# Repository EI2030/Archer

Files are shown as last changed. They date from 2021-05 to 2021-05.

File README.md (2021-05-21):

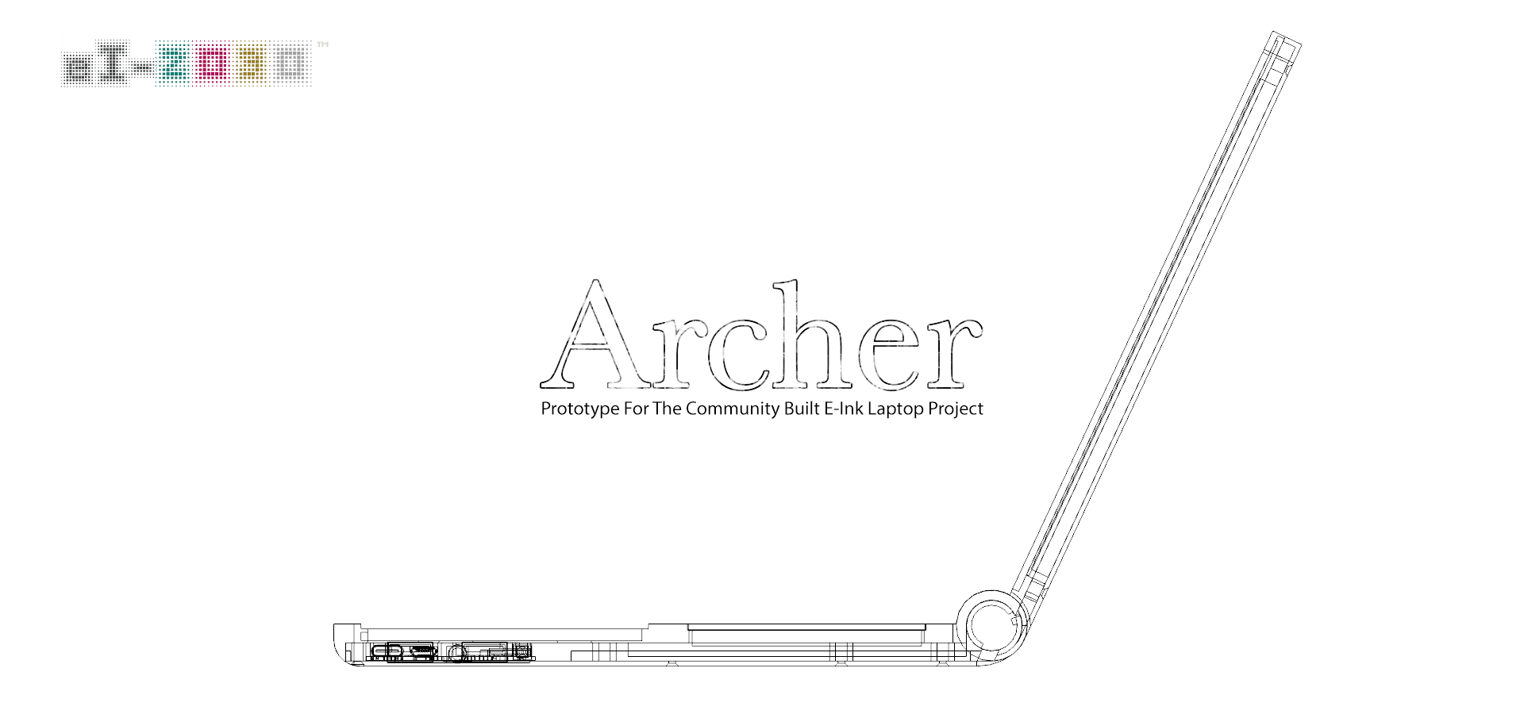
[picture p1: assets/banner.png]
banner


Archer is the codename of our 1st EPD laptop prototype with custom-designed motherboard and 3D-printed chassis.

# Specifications

The specification listed are preliminary and subject to change. Note this is only the specification for the prototype, it does **not** represent the spec for the final product.

- SoC: NXP i.MX 7Dual (2x ARM Cortex-A7 @ 1.2GHz)
- RAM: 2x Micron MT41K256M16 (1GB in total, DDR3)
- Flash: None (prototype designed to always boots from TF card)
- HDD: None
- Network: RTL8273BS (802.11n + BT)
- Main Screen: E Ink ED103TC2 (10.3" 1872x1404) with capactive touch screen
- Sub Screen: ER-TFT0784-1 (7.84" 1280x400) with capactive touch screen
- Screen Controller: i.MX7 integrated EPDC
- Battery: 2x User replaceable LiFePO4 18650 battery
- EC: LPC55S28
- Ports:
  - USB 2.0 Type A Host x1
  - USB 2.0 Type C UFP with Power Delivery x1
  - USB 2.0 Micro B Serial Debug Console x1
  - TF card slot

# Goals

## Goals of this prototype

- Proof of Concept of a EPD laptop
- Enable early development of EC firmware
- Enable early development of the user software
- Test chassis design ideas
- Verify peripheral circuit design
- Enable future prototype with final processor choice

## Non-Goals

- Archer will not represent the performance level of the final product
- Archer is not optimized for low power consumption

# Progress

## Chassis

R0.1 chassis design in progress. Not yet printed.

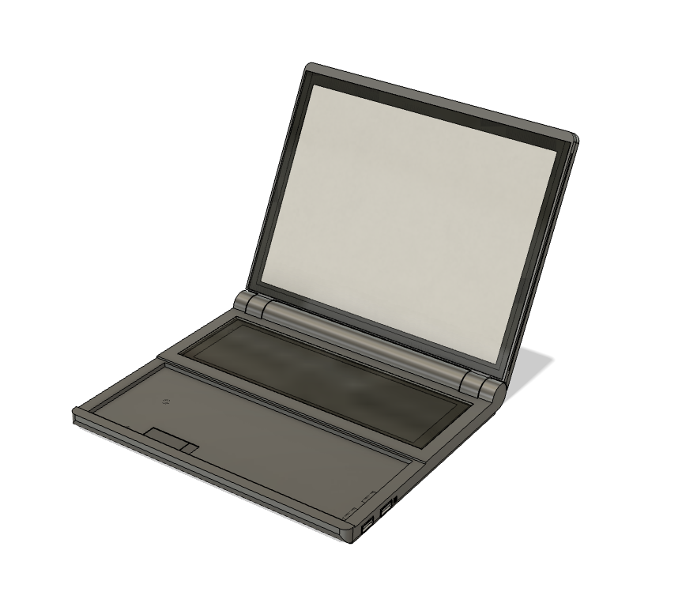
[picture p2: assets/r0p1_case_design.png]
case-design


## Motherboard

R0.1 PCB design finished. Sent to fab.

# Legalese

E Ink® is a registered trademark by E Ink Corporation. All other trademarks are property of their respective owner.

# License

The hardware design is released under the CERN Open Source Hardware License strongly-reciprocal variant, CERN-OHL-S. A copy of the license is provided in the source repository. Additionally, user guide of the license is provided on ohwr.org.

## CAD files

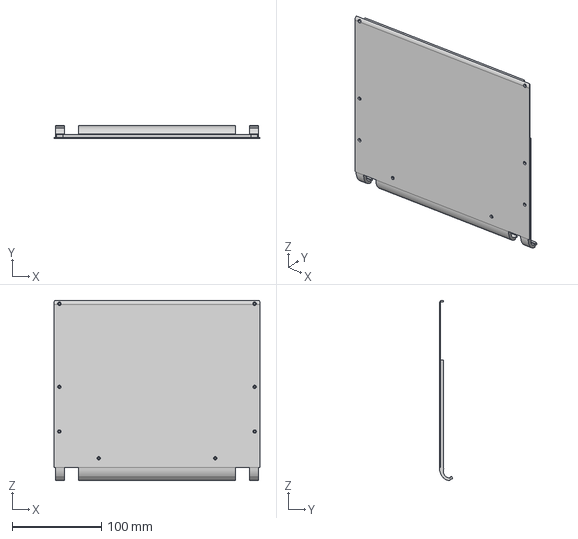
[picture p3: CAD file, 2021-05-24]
chassis/D_case.step
230.6 x 15.0 x 201.8 mm

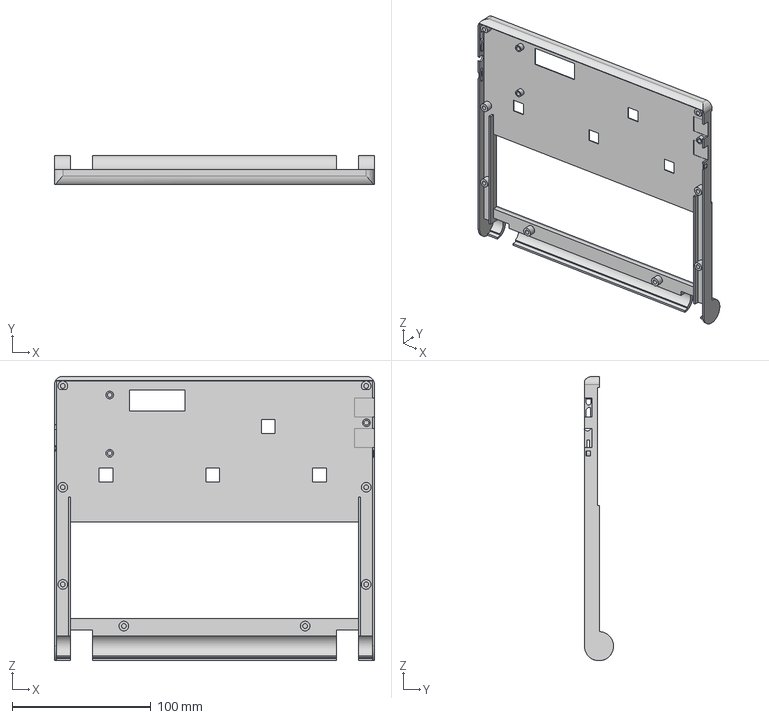
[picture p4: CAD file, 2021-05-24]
chassis/C_case.step
230.6 x 21.0 x 205.0 mm

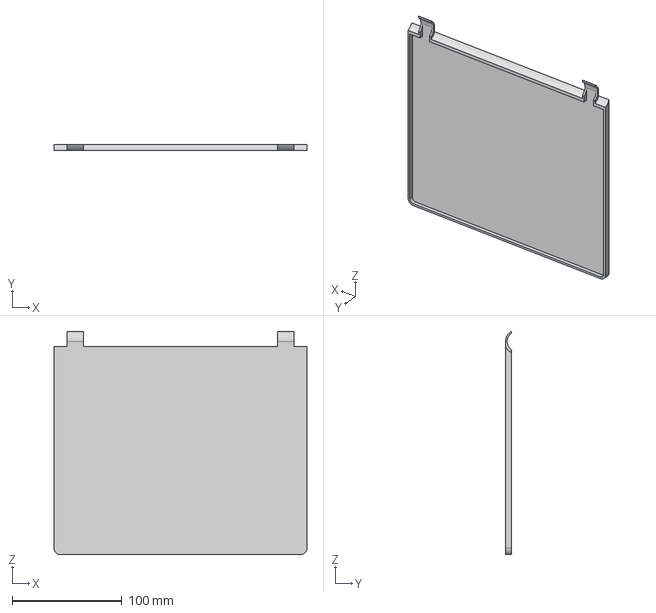
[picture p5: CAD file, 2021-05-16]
chassis/A_case.step
230.6 x 5.40 x 203.7 mm

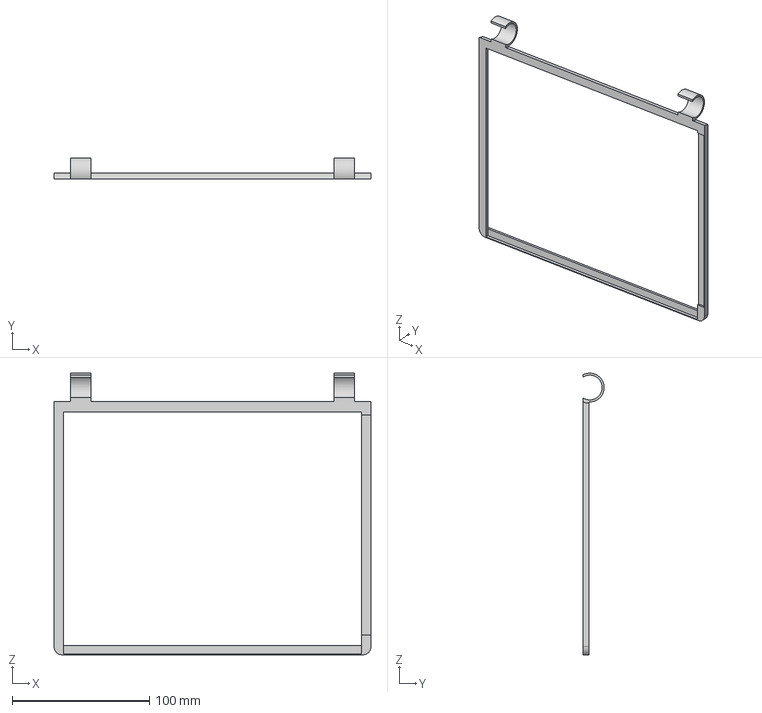
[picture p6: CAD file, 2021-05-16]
chassis/B_case.step
230.6 x 15.6 x 205.0 mm

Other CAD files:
chassis/A_case.f3d
chassis/B_case.f3d
chassis/C_case.f3d
chassis/D_case.f3d

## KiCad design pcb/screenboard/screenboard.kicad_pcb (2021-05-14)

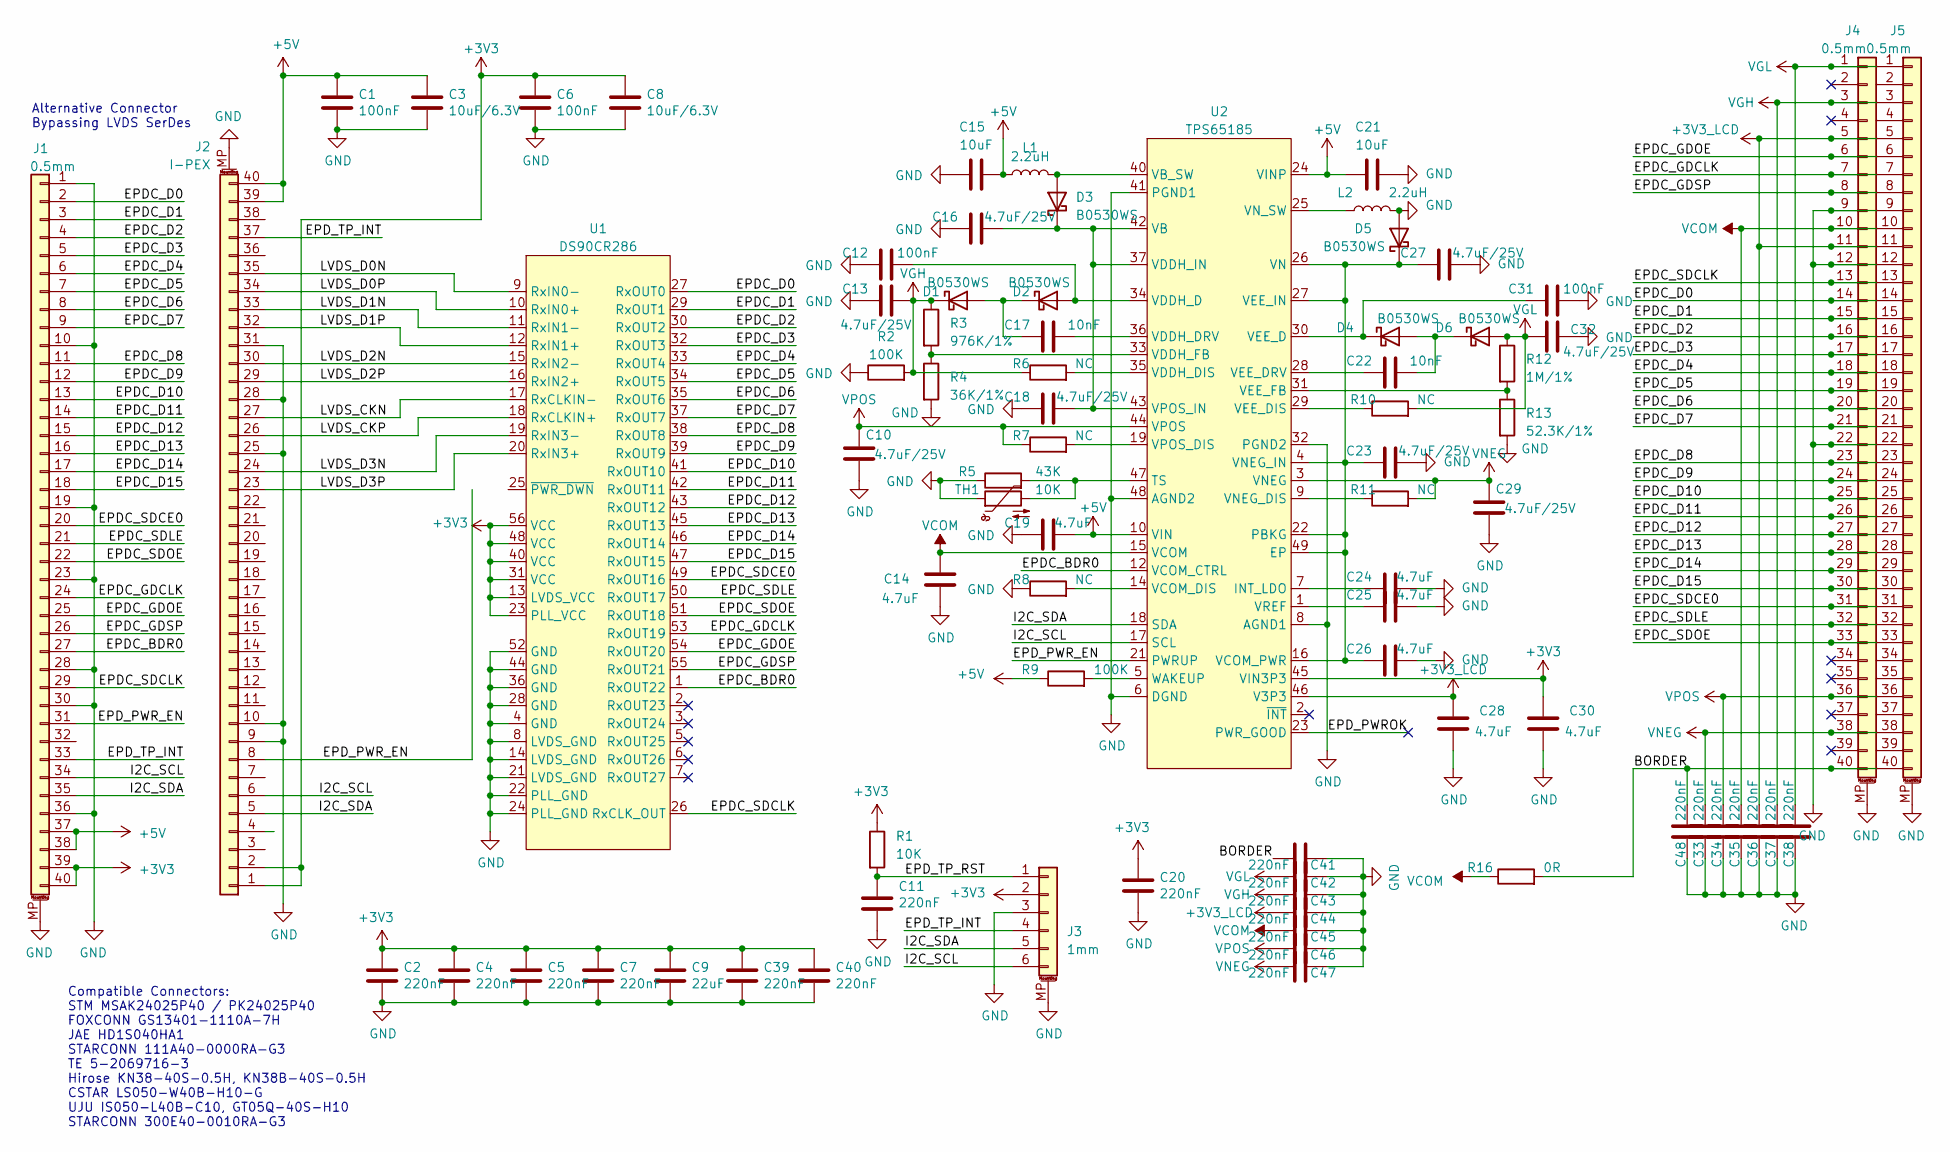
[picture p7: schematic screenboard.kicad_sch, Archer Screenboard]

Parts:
C1, C6, C12, C31: 100nF; C_0402_1005Metric
C2, C4, C5, C7, C11, C20, C33, C34, C35, C36, C37, C38, C39, C40, C41, C42, C43, C44, C45, C46, C47, C48: 220nF; C_0402_1005Metric
C3, C8: 10uF/6.3V; C_0603_1608Metric
C9: 22uF; C_0603_1608Metric
C10, C13, C16, C18, C23, C27, C29, C32: 4.7uF/25V; C_0805_2012Metric
C14, C19, C24, C25, C26, C28, C30: 4.7uF; C_0603_1608Metric
C15, C21: 10uF; C_0603_1608Metric
C17, C22: 10nF; C_0402_1005Metric
D1, D2, D3, D4, D5, D6: B0530WS; D_SOD-323
J1: 0.5mm; Hirose_FH12-40S-0.5SH_1x40-1MP_P0.50mm_Horizontal
J2: I-PEX; TE_5-2069716-3_1x40-1MP_P0.5mm_Horizontal
J3: 1mm; Molex_200528-0060_1x06-1MP_P1.00mm_Horizontal_Reversed
J4, J5: 0.5mm; Hirose_FH12-40S-0.5SH_1x40-1MP_P0.50mm_Horizontal_Reversed
L1, L2: 2.2uH; L_Vishay_IHLP-1212
R1: 10K; R_0402_1005Metric
R2, R9: 100K; R_0402_1005Metric
R3: 976K/1%; R_0402_1005Metric
R4: 36K/1%; R_0402_1005Metric
R5: 43K; R_0402_1005Metric
R6, R7, R8, R10, R11: NC; R_0402_1005Metric
R12: 1M/1%; R_0402_1005Metric
R13: 52.3K/1%; R_0402_1005Metric
R16: 0R; R_0402_1005Metric
TH1: 10K; R_0402_1005Metric
U1: DS90CR286; TSSOP-56_6.1x14mm_P0.5mm
U2: TPS65185; QFN-48-1EP_7x7mm_P0.5mm_EP4.1x4.1mm_ThermalVias

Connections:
+3V3: C2.1, C4.1, C5.1, C6.1, C7.1, C8.1, C9.1, C20.1, C30.1, C39.1, C40.1, J1.39, J1.40, J2.1, J2.2, J3.2, R1.1, U1.13 (LVDS_VCC), U1.23 (PLL_VCC), U1.31 (VCC), U1.40 (VCC), U1.48 (VCC), U1.56 (VCC), U2.45 (VIN3P3)
+3V3_LCD: C28.1, C36.1, C44.1, J4.5, J4.11, J5.5, J5.11, U2.46 (V3P3)
+5V: C1.1, C3.1, C15.2, C19.2, C21.1, J1.37, J1.38, J2.39, J2.40, L1.1, R9.1, U2.10 (VIN), U2.24 (VINP)
/BORDER: C41.1, C48.1, J4.40, J5.40, R16.2
/EPDC_BDR0: J1.27, U1.1 (RxOUT22), U2.12 (VCOM_CTRL)
/EPDC_D0: J1.2, J4.14, J5.14, U1.27 (RxOUT0)
/EPDC_D1: J1.3, J4.15, J5.15, U1.29 (RxOUT1)
/EPDC_D2: J1.4, J4.16, J5.16, U1.30 (RxOUT2)
/EPDC_D3: J1.5, J4.17, J5.17, U1.32 (RxOUT3)
/EPDC_D4: J1.6, J4.18, J5.18, U1.33 (RxOUT4)
/EPDC_D5: J1.7, J4.19, J5.19, U1.34 (RxOUT5)
/EPDC_D6: J1.8, J4.20, J5.20, U1.35 (RxOUT6)
/EPDC_D7: J1.9, J4.21, J5.21, U1.37 (RxOUT7)
/EPDC_D8: J1.11, J4.23, J5.23, U1.38 (RxOUT8)
/EPDC_D9: J1.12, J4.24, J5.24, U1.39 (RxOUT9)
/EPDC_D10: J1.13, J4.25, J5.25, U1.41 (RxOUT10)
/EPDC_D11: J1.14, J4.26, J5.26, U1.42 (RxOUT11)
/EPDC_D12: J1.15, J4.27, J5.27, U1.43 (RxOUT12)
/EPDC_D13: J1.16, J4.28, J5.28, U1.45 (RxOUT13)
/EPDC_D14: J1.17, J4.29, J5.29, U1.46 (RxOUT14)
/EPDC_D15: J1.18, J4.30, J5.30, U1.47 (RxOUT15)
/EPDC_GDCLK: J1.24, J4.7, J5.7, U1.53 (RxOUT19)
/EPDC_GDOE: J1.25, J4.6, J5.6, U1.54 (RxOUT20)
/EPDC_GDSP: J1.26, J4.8, J5.8, U1.55 (RxOUT21)
/EPDC_SDCE0: J1.20, J4.31, J5.31, U1.49 (RxOUT16)
/EPDC_SDCLK: J1.29, J4.13, J5.13, U1.26 (RxCLK_OUT)
/EPDC_SDLE: J1.21, J4.32, J5.32, U1.50 (RxOUT17)
/EPDC_SDOE: J1.22, J4.33, J5.33, U1.51 (RxOUT18)
/EPD_PWR_EN: J1.31, J2.8, U2.21 (PWRUP)
/EPD_TP_INT: J1.33, J2.37, J3.4
/EPD_TP_RST: C11.1, J3.1, R1.2
/I2C_SCL: J1.34, J2.6, J3.6, U2.17 (SCL)
/I2C_SDA: J1.35, J2.5, J3.5, U2.18 (SDA)
/LVDS_CKN: J2.27, U1.17 (RxCLKIN-)
/LVDS_CKP: J2.26, U1.18 (RxCLKIN+)
/LVDS_D0N: J2.35, U1.9 (RxIN0-)
/LVDS_D0P: J2.34, U1.10 (RxIN0+)
/LVDS_D1N: J2.33, U1.11 (RxIN1-)
/LVDS_D1P: J2.32, U1.12 (RxIN1+)
/LVDS_D2N: J2.30, U1.15 (RxIN2-)
/LVDS_D2P: J2.29, U1.16 (RxIN2+)
/LVDS_D3N: J2.24, U1.19 (RxIN3-)
/LVDS_D3P: J2.23, U1.20 (RxIN3+)
GND: C1.2, C2.2, C3.2, C4.2, C5.2, C6.2, C7.2, C8.2, C9.2, C10.1, C11.2, C12.1, C13.1, C14.1, C15.1, C16.1, C18.1, C19.1, C20.2, C21.2, C23.2, C24.2, C25.2, C26.2, C27.2, C28.2, C29.1, C30.2, C31.2, C32.1, C33.2, C34.2, C35.2, C36.2, C37.2, C38.2, C39.2, C40.2, C41.2, C42.2, C43.2, C44.2, C45.2, C46.2, C47.2, C48.2, D5.2 (A), J1.1, J1.10, J1.19, J1.23, J1.28, J1.30, J1.36, J1.MP (MountPin), J2.9, J2.10, J2.25, J2.28, J2.31, J2.MP (MountPin), J3.3, J3.MP (MountPin), J4.9, J4.12, J4.22, J4.MP (MountPin), J5.9, J5.12, J5.22, J5.MP (MountPin), L2.2, R2.1, R4.2, R5.1, R8.1, R13.2, TH1.1, U1.4 (GND), U1.8 (LVDS_GND), U1.14 (LVDS_GND), U1.21 (LVDS_GND), U1.22 (PLL_GND), U1.24 (PLL_GND), U1.28 (GND), U1.36 (GND), U1.44 (GND), U1.52 (GND), U2.6 (DGND), U2.8 (AGND1), U2.32 (PGND2), U2.41 (PGND1), U2.48 (AGND2)
unnamed: C12.2, D2.2 (A), U2.34 (VDDH_D)
unnamed: C16.2, C18.2, D3.1 (K), U2.37 (VDDH_IN), U2.42 (VB), U2.43 (VPOS_IN)
unnamed: C17.1, D1.2 (A), D2.1 (K)
unnamed: C17.2, U2.36 (VDDH_DRV)
unnamed: C22.1, U2.28 (VEE_DRV)
unnamed: C22.2, D4.2 (A), D6.1 (K)
unnamed: C23.1, C26.1, C27.1, D5.1 (K), U2.4 (VNEG_IN), U2.16 (VCOM_PWR), U2.22 (PBKG), U2.26 (VN), U2.27 (VEE_IN), U2.49 (EP)
unnamed: C24.1, U2.7 (INT_LDO)
unnamed: C25.1, U2.1 (VREF)
unnamed: C31.1, D4.1 (K), U2.30 (VEE_D)
unnamed: D3.2 (A), L1.2, U2.40 (VB_SW)
unnamed: L2.1, U2.25 (VN_SW)
unnamed: R3.2, R4.1, U2.33 (VDDH_FB)
unnamed: R5.2, TH1.2, U2.47 (TS)
unnamed: R6.2, U2.35 (VDDH_DIS)
unnamed: R7.2, U2.19 (VPOS_DIS)
unnamed: R8.2, U2.14 (VCOM_DIS)
unnamed: R9.2, U2.5 (WAKEUP)
unnamed: R10.1, U2.29 (VEE_DIS)
unnamed: R11.1, U2.9 (VNEG_DIS)
unnamed: R12.2, R13.1, U2.31 (VEE_FB)
VCOM: C14.2, C35.1, C45.1, J4.10, J5.10, R16.1, U2.15 (VCOM)
VGH: C13.2, C37.1, C43.1, D1.1 (K), J4.3, J5.3, R2.2, R3.1, R6.1
VGL: C32.2, C38.1, C42.1, D6.2 (A), J4.1, J5.1, R10.2, R12.1
VNEG: C29.2, C33.1, C47.1, J4.38, J5.38, R11.2, U2.3 (VNEG)
VPOS: C10.2, C34.1, C46.1, J4.36, J5.36, R7.1, U2.44 (VPOS)

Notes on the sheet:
Alternative Connector Bypassing LVDS SerDes
Compatible Connectors: STM MSAK24025P40 / PK24025P40 FOXCONN GS13401-1110A-7H JAE HD1S040HA1 STARCONN 111A40-0000RA-G3 TE 5-2069716-3 Hirose KN38-40S-0.5H, KN38B-40S-0.5H CSTAR LS050-W40B-H10-G UJU IS050-L40B-C10, GT05Q-40S-H10 STARCONN 300E40-0010RA-G3

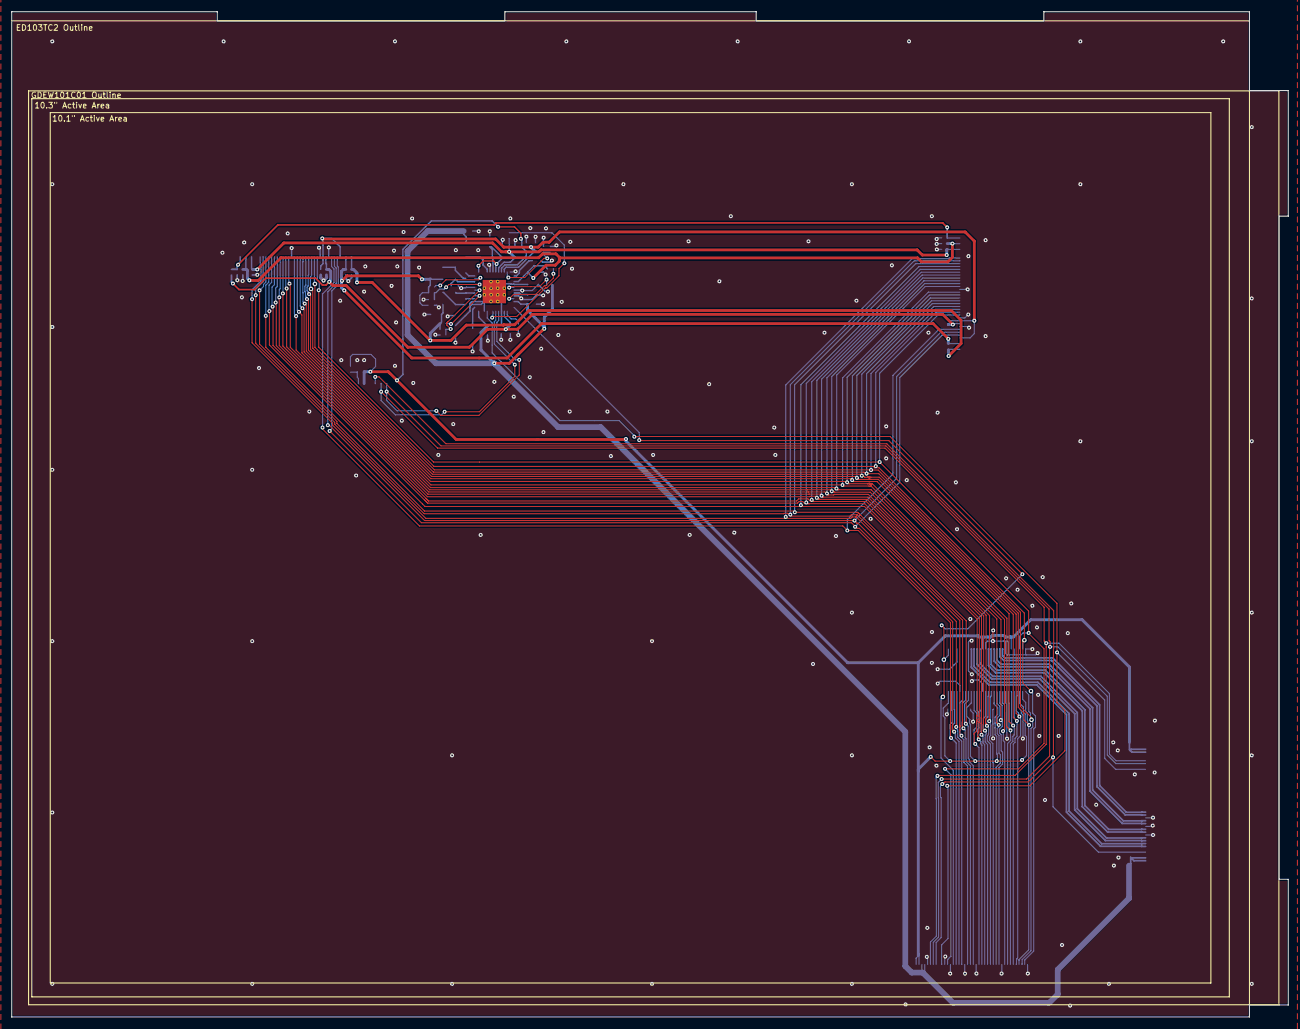
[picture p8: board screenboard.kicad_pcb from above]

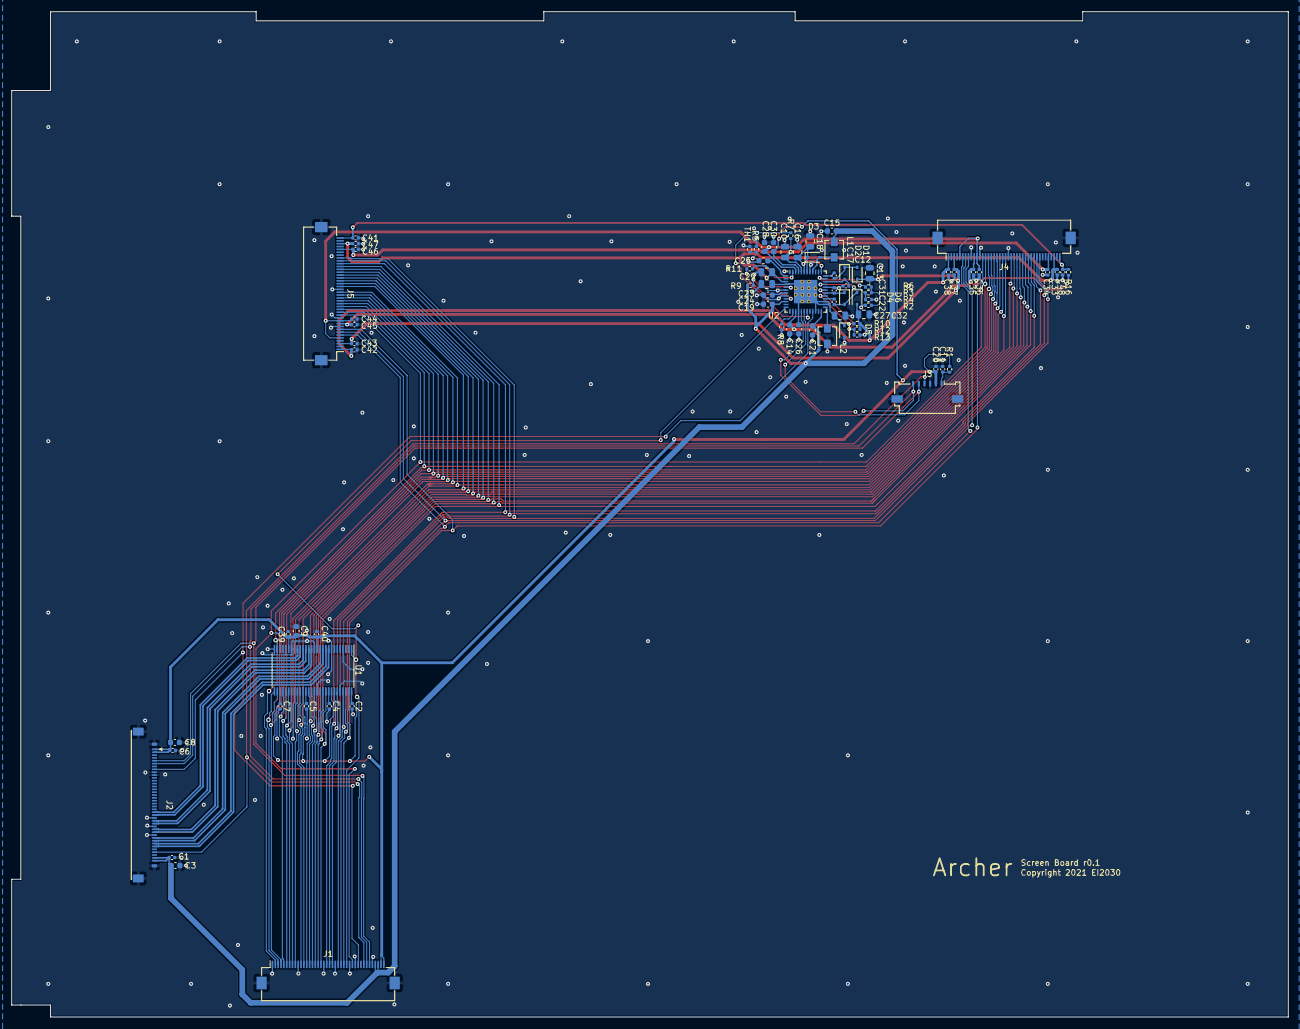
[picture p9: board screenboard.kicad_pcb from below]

Board: 2 copper layers, 223.5 x 176.0 mm, 78 parts (78 on the bottom side), 70 nets.

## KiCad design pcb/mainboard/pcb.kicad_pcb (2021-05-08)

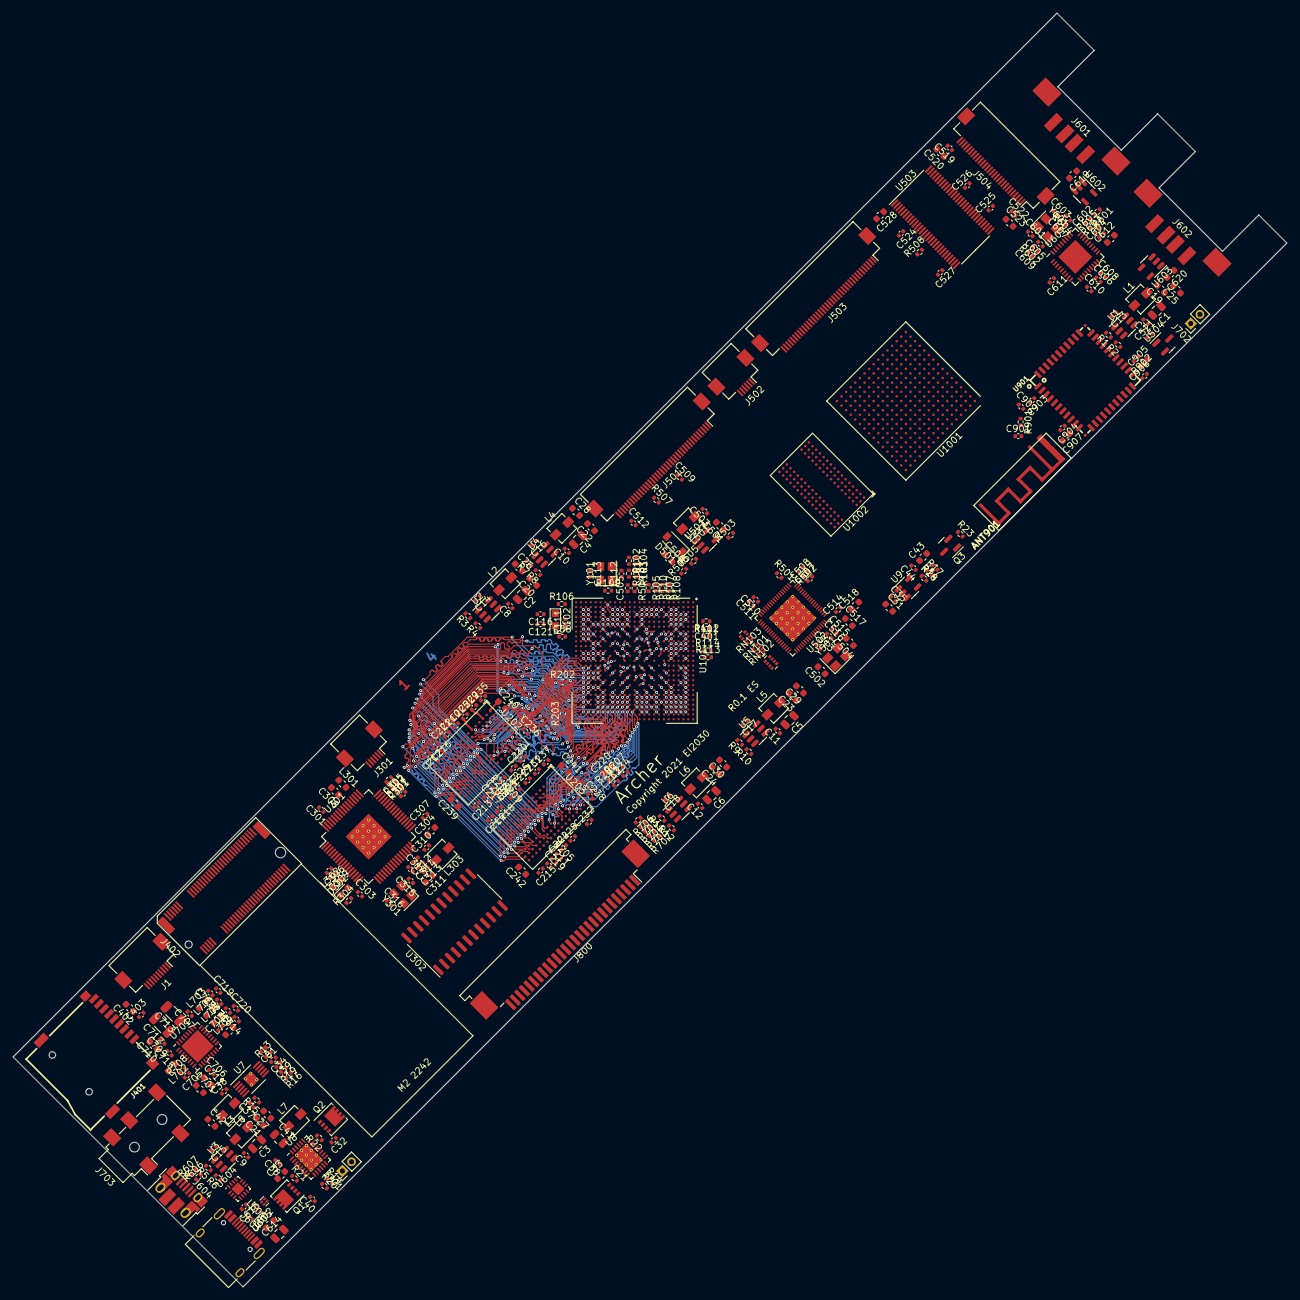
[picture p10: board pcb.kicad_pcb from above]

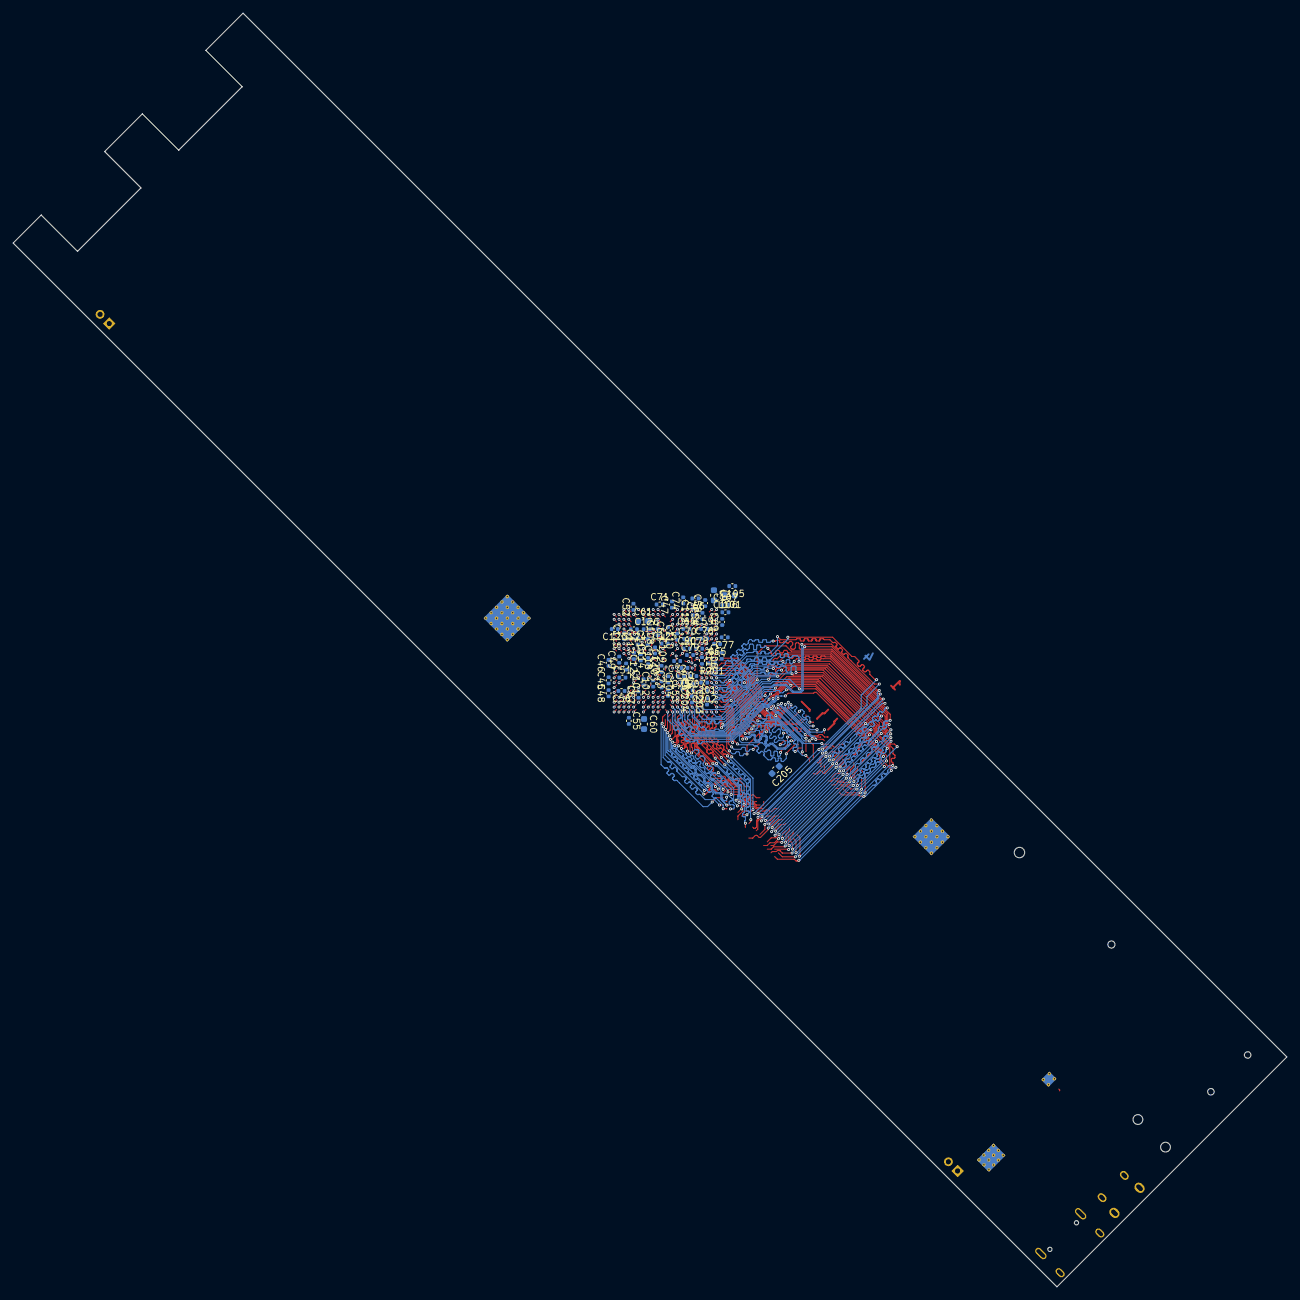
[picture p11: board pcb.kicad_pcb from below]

Board: 4 copper layers, 195.9 x 195.9 mm, 388 parts (68 on the bottom side), 385 nets.

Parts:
ANT901: PCB_WIFI_ANT; bt_antenna_1ant_2gnd
C1, C2, C3, C4, C5, C6: 4.7uF/25V; C_0805_2012Metric
C7, C8, C9, C10, C11, C12, C13, C14, C15, C16, C17, C18, C35, C37, C38, C40, C44, C206, C233, C234, C301, C302, C303, C305, C306, C307, C313, C317, C403, C503, C509, C512, C519, C521, C522, C602, C604, C605, C606, C607, C608, C609, C610, C611, C613, C714, C715, C716, C717, C718, C904, C906: 100nF; C_0402_1005Metric
C19, C20, C21, C22, C23, C24, C25, C26, C27, C28, C29, C30, C31, C42, C308, C501, C905, C907: 10uF; C_0603_1608Metric
C32, C81: 1uF; C_0402_1005Metric
C33, C43, C220, C710, C711: 4.7uF; C_0603_1608Metric
C34: 10nF; C_0402_1005Metric
C36: 22nF; C_0402_1005Metric
C39: 10pF; C_0402_1005Metric
C41, C614: 10uF/25V; C_0805_2012Metric
C45, C46, C47, C48, C49, C50, C51, C52, C53, C54, C55, C56, C57, C59, C62, C63, C64, C65, C66, C67, C71, C72, C73, C74, C75, C76, C78, C79, C101, C102, C103, C105, C106, C108, C109, C111, C114, C115, C117, C118, C122, C123, C124, C125, C201, C202, C203, C204, C207, C208, C209, C210, C211, C212, C213, C214, C215, C216, C217, C218, C219, C221, C222, C223, C224, C225, C226, C227, C228, C229, C230, C231, C232, C235, C236, C237, C238, C505, C507, C508, C510, C511, C513, C514, C515, C516, C524, C525, C526, C527: 220nF; C_0402_1005Metric
C58, C68, C69, C70, C77, C80, C104, C107, C110, C119, C120, C126, C309, C314: 2.2uF; C_0402_1005Metric
C60, C61, C205, C239, C240, C241, C242, C304, C311, C402, C517, C518, C528: 22uF; C_0603_1608Metric
C112, C113, C315, C316, C401, C601, C603: 18pF; C_0402_1005Metric
C116, C121: DNP/18pF; C_0402_1005Metric
C310, C312: 47pF; C_0402_1005Metric
C502, C504: 18pF; C_0603_1608Metric
C506: 1uF/35V; C_0603_1608Metric
C520, C523, C612, C619, C620: 10uF/6.3V; C_0603_1608Metric
C705, C706, C707, C708, C709, C719, C720: 470nF; C_0402_1005Metric
C712, C713: 100uF; C_1206_3216Metric
C901, C902: DNP; C_0402_1005Metric
C903: 33pF/50V/5%; C_0402_1005Metric
D302: LED; LED_0603_1608Metric
D501: MBR0530; D_SOD-123
J1: Conn_01x10_MountingPin; Hirose_FH12-10S-0.5SH_1x10-1MP_P0.50mm_Horizontal
J301, J502: Conn_01x06_MountingPin; Hirose_FH12-6S-0.5SH_1x06-1MP_P0.50mm_Horizontal
J401: MICRO_SD(TFC-WPAPR-08); TFC-WPAPR-08
J402: Bus_M.2_Socket_B; M2_BKEY
J501, J503: Conn_01x40_MountingPin; Hirose_FH12-40S-0.5SH_1x40-1MP_P0.50mm_Horizontal
J504: Conn_01x28_MountingPin; Hirose_FH12-28S-0.5SH_1x28-1MP_P0.50mm_Horizontal
J601, J602: USB_A; Connector_USB_905-562A2021S10100
J603: USB_C_Receptacle_USB2.0; USB_C_Receptacle_HRO_TYPE-C-31-M-12
J604: USB_B_Micro; USB_Micro-B_Amphenol_10103594-0001LF_Horizontal
J701, J702: Conn_01x02; PinHeader_1x02_P2.00mm_Vertical
J703: AudioJack3_SwitchT; Jack_3.5mm_PJ327E_5A
J800: Conn_01x28_MountingPin; TE_2-84953-8_1x28-1MP_P1.0mm_Horizontal
L1, L2, L3, L4, L5, L6, L303: 4.7uH; L_Vishay_IHLP-1212
L7: 6.8uH; L_Vishay_IHLP-1212
L8: 10uH; L_Vishay_IHLP-1212
L9, L101, L301, L302, L602, L701, L702: 120R; L_0603_1608Metric
L501: 22uH; L_Vishay_IHLP-1212
L601: EXC14CE900U; L_CommonModeChoke_Panasonic_EXC14CE
L703, L704, L705, L706: 15uH; L_0603_1608Metric
Q1, Q2: FDMC8327L; Diodes_PowerDI3333-8
Q3: 2SK3018; SOT-23
R1, R16: 200K/1%; R_0402_1005Metric
R2, R6, R8, R10, R12: 27K/1%; R_0402_1005Metric
R3, R15: 20K/1%; R_0402_1005Metric
R4: 10K/1%; R_0402_1005Metric
R5: 121K/1%; R_0402_1005Metric
R7, R9: 22.6K/1%; R_0402_1005Metric
R11: 34.8K/1%; R_0402_1005Metric
R13, R23, R601, R708: 100K; R_0402_1005Metric
R14: 63.4K; R_0402_1005Metric
R17: 560K/1%; R_0402_1005Metric
R18, R106: 100K/1%; R_0402_1005Metric
R19: 649K/1%; R_0402_1005Metric
R20, R101, R104, R105, R107, R108, R110, R113, R202, R203, R301, R302, R501, R502, R503, R505, R508, R604, R902: 10K; R_0402_1005Metric
R21, R22: 0.016R; R_0402_1005Metric
R24: 487K/1%; R_0402_1005Metric
R102, R103: DNP/10K; R_0402_1005Metric
R109: 1M; R_0402_1005Metric
R111: DNP/4.75M; R_0402_1005Metric
R112, R114: 200/1%; R_0402_1005Metric
R115: 4.7K/1%; R_0402_1005Metric
R201, R204, R205: 240R 1%; R_0402_1005Metric
R206, R207: 1.5K/0.5%; R_0402_1005Metric
R304, R506: 1K; R_0402_1005Metric
R401: 33; R_0402_1005Metric
R504: 49.9K/1%; R_0402_1005Metric
R507: 3R; R_0402_1005Metric
R602: 12K/1%; R_0402_1005Metric
R603, R605: DNP; R_0402_1005Metric
R606, R607: 22; R_0402_1005Metric
R703, R704, R705, R706, R707: 22R; R_0402_1005Metric
R901: 0R; R_0402_1005Metric
RN101, RN102, RN103: 10K; R_Array_Convex_4x0402
U1, U2, U3, U4, U5, U6: SY8120; TSOT-23-6
U7: LT8606; MSOP-10-1EP_3x3mm_P0.5mm_EP1.68x1.88mm_ThermalVias
U8: LTC4162-F; QFN-28-1EP_4x5mm_P0.5mm_EP2.65x3.65mm_ThermalVias
U9: ADP123; TSOT-23-5
U101: MCIMX7S5EVM08SC; BGA-541_25x25_19.0x19.0mm
U202, U203: MT41K256M16HA; BGA-96_9.0x13.0mm_Layout2x3x16_P0.8mm
U301: LPC5500_FBD64; LQFP-64-1EP_10x10mm_P0.5mm_EP5x5mm_ThermalVias
U302: 74LS154; SO-24_5.3x15mm_P1.27mm
U501: CAT4139; SOT-23-5
U502: SSD2828; QFN-68-1EP_8x8mm_P0.4mm_EP5.2x5.2mm_ThermalVias
U503: DS90C385A; TSSOP-56_6.1x14mm_P0.5mm
U504: SM351LT; SOT-23
U601: USB2514B_Bi; QFN-36-1EP_6x6mm_P0.5mm_EP3.7x3.7mm
U602, U603: AP2171W; SOT-23-5
U604: FUSB302BMPX; WQFN-14-1EP_2.5x2.5mm_P0.5mm_EP1.45x1.45mm
U605: USBLC6-2P6; SOT-666
U701: WM8960; QFN-32-1EP_5x5mm_P0.5mm_EP3.6x3.6mm
U901: RTL8723BS; RL-SM02BD(RTL8723BS)
U1001: DNP/XC7A15T-FTG256; Xilinx_FTG256
U1002: DNP/MT41K64M16HA; BGA-96_9.0x13.0mm_Layout2x3x16_P0.8mm
Y101: 24MHz; Oscillator_SMD_Abracon_ASE-4Pin_3.2x2.5mm
Y102: 32.768kHz; Crystal_SMD_TXC_9HT11-2Pin_2.0x1.2mm_HandSoldering
Y301: 16MHz; Oscillator_SMD_Abracon_ASE-4Pin_3.2x2.5mm
Y501, Y601: 24MHz; Crystal_SMD_3225-4Pin_3.2x2.5mm

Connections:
+1V0: C22.2, C28.2, C46.1, C47.1, C49.1, C50.1, C52.1, C53.1, C56.1, C57.1, C61.1, C62.1, C71.1, C72.1, C73.1, C74.1, C75.1, L4.2, R7.2, U101.C14 (VDD_SOC_IN), U101.D14 (VDD_SOC_IN), U101.F3 (VDD_SOC_IN), U101.F4 (VDD_SOC_IN), U101.F18 (VDD_SOC_IN), U101.F19 (VDD_SOC_IN), U101.J3 (VDD_SOC_IN), U101.J4 (VDD_SOC_IN), U101.M3 (VDD_SOC_IN), U101.M4 (VDD_SOC_IN), U101.P18 (VDD_SOC_IN), U101.R3 (VDD_SOC_IN), U101.R4 (VDD_SOC_IN), U101.R17 (VDD_SOC_IN), U101.T18 (VDD_SOC_IN), U101.U13 (VDD_SOC_IN), U101.U15 (VDD_SOC_IN), U101.U17 (VDD_SOC_IN), U101.V12 (VDD_SOC_IN), U101.V14 (VDD_SOC_IN), U101.V16 (VDD_SOC_IN), U101.V18 (VDD_SOC_IN)
+1V2: C507.1, C510.1, C513.1, C515.1, C517.1, U502.15 (MVDD), U502.31 (MVDD), U502.60 (MVDD), U502.66 (MVDD)
+1V8: C20.2, C26.2, C59.1, C101.1, C105.1, C109.1, C508.1, C509.1, C511.1, C514.1, C516.1, C518.1, C705.1, J501.18, J501.19, L2.2, L9.1, L101.1, R3.2, U101.K18 (NVCC_LCD), U101.L9 (NVCC_SPI), U101.V8 (FUSE_FSOURCE), U101.W6 (VDD_LPSR_IN), U502.16 (VDDIO), U502.33 (VDDIO), U502.64 (VDDIO), U502.68 (VDDIO), U701.8 (DCVDD)
+1V8A: C54.1, C58.1, C111.1, L9.2, U101.V5 (VDD_XTAL_1P8), U101.V6 (VDDA_1P8), U101.W5 (VDDA_1P8)
+1V35: C24.2, C30.2, C201.1, C202.1, C203.1, C204.1, C205.1, C207.1, C212.1, C213.1, C214.1, C215.1, C216.1, C217.1, C218.1, C219.1, C220.1, C221.1, C222.1, C223.1, C224.1, C225.1, C226.1, C227.1, C228.1, C229.1, C230.1, C231.1, C232.1, C233.1, C235.1, C236.1, C237.1, C238.1, C239.1, C240.1, C241.1, C242.1, L6.2, R11.2, R206.1, U101.AA16 (NVCC_DRAM), U101.AA17 (NVCC_DRAM), U101.AA18 (NVCC_DRAM), U101.AA19 (NVCC_DRAM), U101.AA20 (NVCC_DRAM), U101.AA21 (NVCC_DRAM), U101.T21 (NVCC_DRAM), U101.U21 (NVCC_DRAM), U101.V21 (NVCC_DRAM), U101.W21 (NVCC_DRAM), U101.Y20 (NVCC_DRAM_CKE), U101.Y21 (NVCC_DRAM), U202.A1 (VDDQ), U202.A8 (VDDQ), U202.B2 (VDD), U202.C1 (VDDQ), U202.C9 (VDDQ), U202.D2 (VDDQ), U202.D9 (VDD), U202.E9 (VDDQ), U202.F1 (VDDQ), U202.G7 (VDD), U202.H2 (VDDQ), U202.H9 (VDDQ), U202.K2 (VDD), U202.K8 (VDD), U202.N1 (VDD), U202.N9 (VDD), U202.R1 (VDD), U202.R9 (VDD), U203.A1 (VDDQ), U203.A8 (VDDQ), U203.B2 (VDD), U203.C1 (VDDQ), U203.C9 (VDDQ), U203.D2 (VDDQ), U203.D9 (VDD), U203.E9 (VDDQ), U203.F1 (VDDQ), U203.G7 (VDD), U203.H2 (VDDQ), U203.H9 (VDDQ), U203.K2 (VDD), U203.K8 (VDD), U203.N1 (VDD), U203.N9 (VDD), U203.R1 (VDD), U203.R9 (VDD), U1002.A1 (VDDQ), U1002.A8 (VDDQ), U1002.B2 (VDD), U1002.C1 (VDDQ), U1002.C9 (VDDQ), U1002.D2 (VDDQ), U1002.D9 (VDD), U1002.E9 (VDDQ), U1002.F1 (VDDQ), U1002.G7 (VDD), U1002.H2 (VDDQ), U1002.H9 (VDDQ), U1002.K2 (VDD), U1002.K8 (VDD), U1002.N1 (VDD), U1002.N9 (VDD), U1002.R1 (VDD), U1002.R9 (VDD)
+3V3: C21.2, C27.2, C63.1, C64.1, C102.1, C103.1, C108.1, C114.1, C115.1, C122.1, C124.1, C125.1, C402.1, C403.1, C512.1, C519.1, C520.1, C521.1, C524.1, C525.1, C526.1, C527.1, C528.1, C604.1, C607.1, C608.1, C609.1, C610.1, C611.1, C612.1, C904.1, C905.1, C906.1, C907.1, J401.4 (VDD), J501.38, J501.39, J502.3, J503.39, J503.40, J504.27, J504.28, L3.2, L701.2, L702.2, R5.2, R105.1, R107.1, R108.1, R110.1, R508.1, R601.1, R604.2, R902.1, RN101.5 (R4.2), RN101.6 (R3.2), RN101.7 (R2.2), RN101.8 (R1.2), U101.F9 (VDD_USB_OTG2_3P3_IN), U101.F10 (VDD_USB_OTG1_3P3_IN), U101.F12 (NVCC_SAI), U101.H8 (NVCC_SD2), U101.K8 (NVCC_SD3), U101.L17 (NVCC_EPDC2), U101.M8 (NVCC_I2C), U101.M18 (NVCC_EPDC1), U101.N9 (NVCC_UART), U101.P8 (NVCC_GPIO1), U101.T8 (NVCC_GPIO2), U503.1 (VCC), U503.9 (VCC), U503.26 (VCC), U503.34 (PLL_VCC), U503.44 (LVDS_VCC), U504.1 (VCC), U601.5 (VDDA33), U601.10 (VDDA33), U601.15 (VDD33), U601.23 (VDD33), U601.27 (VBUS_DET), U601.29 (VDDA33), U601.36 (VDDA33), U901.9 (VDD33), U901.22 (VDD_IO)
+3V3_SB: C39.1, C42.2, C301.1, C304.1, C307.1, C310.1, C317.1, C613.1, J301.1, L8.2, L301.1, L302.1, R13.2, R19.1, R101.2, R103.2, R301.1, R302.1, U8.15 (DVCC), U101.AD8 (VDD_SNVS_IN), U301.25 (USB1_VBUS), U301.27 (USB1_3V3), U301.32 (VBAT_DCDC), U301.33 (VBAT_PMU), U301.61 (USB0_3V3), U302.24 (VCC), U604.3 (VDD), U604.4 (VDD), U604.12 (VCONN), U604.13 (VCONN)
+5V: C19.2, C25.2, C31.1, C35.1, C501.2, C503.2, C522.1, C523.1, J503.37, J503.38, J504.1, J504.2, L1.2, L501.1, R1.2, U9.1 (VIN), U9.3 (EN), U501.5 (IN), U602.5 (IN), U603.5 (IN)
+DRAM_VREF: C206.1, C208.1, C209.1, C210.1, C211.1, C233.2, C234.1, R206.2, R207.1, U101.AC13 (DRAM_VREF), U202.H1 (VrefDQ), U202.M8 (VrefCA), U203.H1 (VrefDQ), U203.M8 (VrefCA)
+SYS: C1.2, C2.2, C3.2, C4.2, C5.2, C6.2, C7.2, C8.2, C9.2, C10.2, C11.2, C12.2, C41.2, C81.2, Q2.5 (D), R21.1, U1.5 (VIN), U2.5 (VIN), U3.5 (VIN), U4.5 (VIN), U5.5 (VIN), U6.5 (VIN), U7.9 (VIN), U7.10 (EN/UV), U8.3 (VOUTA), U8.4 (CLN), U8.27 (VOUT), U8.28 (VOUT)
+VCCIO_SD: C43.1, C44.1, R17.1, R24.1, U9.5 (VOUT)
+VCCIO_WL: C123.1, U101.E7 (NVCC_SD1)
/audio/MICBIAS: C715.1, U701.1 (MICBIAS)
/ddr/DRAM_ADDR0: U101.AB19 (DRAM_ADDR0), U202.N3 (A0), U203.N3 (A0)
/ddr/DRAM_ADDR1: U101.AB16 (DRAM_ADDR1), U202.P7 (A1), U203.P7 (A1)
/ddr/DRAM_ADDR2: U101.AC18 (DRAM_ADDR2), U202.P3 (A2), U203.P3 (A2)
/ddr/DRAM_ADDR3: U101.AC20 (DRAM_ADDR3), U202.N2 (A3), U203.N2 (A3)
/ddr/DRAM_ADDR4: U101.AB21 (DRAM_ADDR4), U202.P8 (A4), U203.P8 (A4)
/ddr/DRAM_ADDR5: U101.Y23 (DRAM_ADDR5), U202.P2 (A5), U203.P2 (A5)
/ddr/DRAM_ADDR6: U101.V22 (DRAM_ADDR6), U202.R8 (A6), U203.R8 (A6)
/ddr/DRAM_ADDR7: U101.Y22 (DRAM_ADDR7), U202.R2 (A7), U203.R2 (A7)
/ddr/DRAM_ADDR8: U101.W22 (DRAM_ADDR8), U202.T8 (A8), U203.T8 (A8)
/ddr/DRAM_ADDR9: U101.V23 (DRAM_ADDR9), U202.R3 (A9), U203.R3 (A9)
/ddr/DRAM_ADDR10: U101.T23 (DRAM_ADDR10), U202.L7 (A10), U203.L7 (A10)
/ddr/DRAM_ADDR11: U101.U22 (DRAM_ADDR11), U202.R7 (A11), U203.R7 (A11)
/ddr/DRAM_ADDR12: U101.T22 (DRAM_ADDR12), U202.N7 (A12/~BC), U203.N7 (A12/~BC)
/ddr/DRAM_ADDR13: U101.P23 (DRAM_ADDR13), U202.T3 (A13), U203.T3 (A13)
/ddr/DRAM_ADDR14: U101.AB18 (DRAM_ADDR14), U202.T7 (A14/NC), U203.T7 (A14/NC)
/ddr/DRAM_BA0: U101.R22 (DRAM_SDBA0), U202.M2 (BA0), U203.M2 (BA0)
/ddr/DRAM_BA1: U101.P22 (DRAM_SDBA1), U202.N8 (BA1), U203.N8 (BA1)
/ddr/DRAM_BA2: U101.N23 (DRAM_SDBA2), U202.M3 (BA2), U203.M3 (BA2)
/ddr/DRAM_CASB: U101.AC14 (~DRAM_CAS), U202.K3 (~CAS), U203.K3 (~CAS)
/ddr/DRAM_CKE: R202.2, U101.AB17 (DRAM_SDCKE0), U202.K9 (CKE), U203.K9 (CKE)
/ddr/DRAM_CKN: U101.AD25 (DRAM_SDCLK0_N), U202.K7 (~CK), U203.K7 (~CK)
/ddr/DRAM_CKP: U101.AD24 (DRAM_SDCLK0_P), U202.J7 (CK), U203.J7 (CK)
/ddr/DRAM_CSB: U101.AB23 (~DRAM_CS0), U202.L2 (~CS), U203.L2 (~CS)
/ddr/DRAM_DATA0: U101.AD22 (DRAM_DATA0), U202.A7 (DQ12)
/ddr/DRAM_DATA1: U101.AD23 (DRAM_DATA1), U202.A3 (DQ15)
/ddr/DRAM_DATA2: U101.AE20 (DRAM_DATA2), U202.C2 (DQ11)
/ddr/DRAM_DATA3: U101.AE23 (DRAM_DATA3), U202.A2 (DQ13)
/ddr/DRAM_DATA4: U101.AE22 (DRAM_DATA4), U202.D7 (DQ8)
/ddr/DRAM_DATA5: U101.AD19 (DRAM_DATA5), U202.B8 (DQ14)
/ddr/DRAM_DATA6: U101.AD18 (DRAM_DATA6), U202.C3 (DQ9)
/ddr/DRAM_DATA7: U101.AE19 (DRAM_DATA7), U202.C8 (DQ10)
/ddr/DRAM_DATA8: U101.AE14 (DRAM_DATA8), U202.G2 (DQ6)
/ddr/DRAM_DATA9: U101.AE18 (DRAM_DATA9), U202.E3 (DQ0)
/ddr/DRAM_DATA10: U101.AE17 (DRAM_DATA10), U202.F2 (DQ2)
/ddr/DRAM_DATA11: U101.AD16 (DRAM_DATA11), U202.H3 (DQ4)
/ddr/DRAM_DATA12: U101.AE16 (DRAM_DATA12), U202.H8 (DQ5)
/ddr/DRAM_DATA13: U101.AD14 (DRAM_DATA13), U202.F8 (DQ3)
/ddr/DRAM_DATA14: U101.AD13 (DRAM_DATA14), U202.F7 (DQ1)
/ddr/DRAM_DATA15: U101.AE13 (DRAM_DATA15), U202.H7 (DQ7)
/ddr/DRAM_DATA16: U101.AA25 (DRAM_DATA16), U203.G2 (DQ6)
/ddr/DRAM_DATA17: U101.W24 (DRAM_DATA17), U203.E3 (DQ0)
/ddr/DRAM_DATA18: U101.V25 (DRAM_DATA18), U203.F2 (DQ2)
/ddr/DRAM_DATA19: U101.W25 (DRAM_DATA19), U203.H3 (DQ4)
/ddr/DRAM_DATA20: U101.AC25 (DRAM_DATA20), U203.F8 (DQ3)
/ddr/DRAM_DATA21: U101.AB25 (DRAM_DATA21), U203.F7 (DQ1)
/ddr/DRAM_DATA22: U101.AB24 (DRAM_DATA22), U203.H8 (DQ5)
/ddr/DRAM_DATA23: U101.AC24 (DRAM_DATA23), U203.H7 (DQ7)
/ddr/DRAM_DATA24: U101.R25 (DRAM_DATA24), U203.A2 (DQ13)
/ddr/DRAM_DATA25: U101.N24 (DRAM_DATA25), U203.A7 (DQ12)
/ddr/DRAM_DATA26: U101.P25 (DRAM_DATA26), U203.C2 (DQ11)
/ddr/DRAM_DATA27: U101.N25 (DRAM_DATA27), U203.B8 (DQ14)
/ddr/DRAM_DATA28: U101.U25 (DRAM_DATA28), U203.D7 (DQ8)
/ddr/DRAM_DATA29: U101.R24 (DRAM_DATA29), U203.C8 (DQ10)
/ddr/DRAM_DATA30: U101.U24 (DRAM_DATA30), U203.A3 (DQ15)
/ddr/DRAM_DATA31: U101.V24 (DRAM_DATA31), U203.C3 (DQ9)
/ddr/DRAM_DQM0: U101.AD20 (DRAM_DQM0), U202.D3 (UDM)
/ddr/DRAM_DQM1: U101.AD17 (DRAM_DQM1), U202.E7 (LDM)
/ddr/DRAM_DQM2: U101.AA24 (DRAM_DQM2), U203.E7 (LDM)
/ddr/DRAM_DQM3: U101.P24 (DRAM_DQM3), U203.D3 (UDM)
/ddr/DRAM_ODT: U101.AC16 (DRAM_ODT0), U202.K1 (ODT), U203.K1 (ODT)
/ddr/DRAM_RASB: U101.AB15 (~DRAM_RAS), U202.J3 (~RAS), U203.J3 (~RAS)
/ddr/DRAM_RST: R203.2, U101.AC22 (DRAM_RESET), U202.T2 (~RESET), U203.T2 (~RESET)
/ddr/DRAM_SDQSN_0: U101.AD21 (DRAM_SDQS0_N), U202.B7 (~UDQS)
/ddr/DRAM_SDQSN_1: U101.AE15 (DRAM_SDQS1_N), U202.G3 (~LDQS)
/ddr/DRAM_SDQSN_2: U101.Y25 (DRAM_SDQS2_N), U203.G3 (~LDQS)
/ddr/DRAM_SDQSN_3: U101.T25 (DRAM_SDQS3_N), U203.B7 (~UDQS)
/ddr/DRAM_SDQSP_0: U101.AE21 (DRAM_SDQS0_P), U202.C7 (UDQS)
/ddr/DRAM_SDQSP_1: U101.AD15 (DRAM_SDQS1_P), U202.F3 (LDQS)
/ddr/DRAM_SDQSP_2: U101.Y24 (DRAM_SDQS2_P), U203.F3 (LDQS)
/ddr/DRAM_SDQSP_3: U101.T24 (DRAM_SDQS3_P), U203.C7 (UDQS)
/ddr/DRAM_WEB: U101.AB14 (~DRAM_SDWE), U202.L3 (~WE), U203.L3 (~WE)
/ec/EC_SWCLK: J301.4, U301.6 (PIO0_11)
/ec/EC_SWDIO: J301.5, U301.5 (PIO0_12)
/ec/KSOE: U301.50 (PIO0_22), U302.18 (E0)
/ec/KSOS1: U301.38 (PIO0_18), U302.23 (A0)
/ec/KSOS2: U301.58 (PIO0_19), U302.22 (A1)
/ec/KSOS3: U301.48 (PIO0_20), U302.21 (A2)
/ec/KSOS4: U301.49 (PIO0_21), U302.20 (A3)
/ec/LED: D302.2 (A), U301.13 (PIO0_10)
/lcd/LEDA: C506.2, D501.1 (K), J501.35, J501.36
/lcd/LEDK: J501.28, J501.29, R506.1, R507.1
/lcd/LVDS_CKN: J504.11, U503.40 (TxCLKOUT-)
/lcd/LVDS_CKP: J504.10, U503.39 (TxCLKOUT+)
/lcd/LVDS_D0N: J504.20, U503.48 (TxOUT0-)
/lcd/LVDS_D0P: J504.19, U503.47 (TxOUT0+)
/lcd/LVDS_D1N: J504.17, U503.46 (TxOUT1-)
/lcd/LVDS_D1P: J504.16, U503.45 (TxOUT1+)
/lcd/LVDS_D2N: J504.14, U503.42 (TxOUT2-)
/lcd/LVDS_D2P: J504.13, U503.41 (TxOUT2+)
/lcd/LVDS_D3N: J504.8, U503.38 (TxOUT3-)
/lcd/LVDS_D3P: J504.7, U503.37 (TxOUT3+)
/lcd/MIPI_CN: J501.9, U502.8 (MIPI_CN)
/lcd/MIPI_CP: J501.8, U502.7 (MIPI_CP)
/lcd/MIPI_DN0: J501.3, U502.2 (MIPI_DN0)
/lcd/MIPI_DN1: J501.6, U502.5 (MIPI_DN1)
/lcd/MIPI_DN2: J501.12, U502.11 (MIPI_DN2)
/lcd/MIPI_DN3: J501.15, U502.14 (MIPI_DN3)
/lcd/MIPI_DP0: J501.2, U502.1 (MIPI_DP0)
/lcd/MIPI_DP1: J501.5, U502.4 (MIPI_DP1)
/lcd/MIPI_DP2: J501.11, U502.10 (MIPI_DP2)
/lcd/MIPI_DP3: J501.14, U502.13 (MIPI_DP3)
/power/1V0_ARM: C23.2, C29.2, C45.1, C48.1, C51.1, C55.1, C60.1, L5.2, R9.2, U101.C17 (VDD_ARM_IN), U101.C20 (VDD_ARM_IN), U101.D17 (VDD_ARM_IN), U101.D20 (VDD_ARM_IN), U101.F22 (VDD_ARM_IN), U101.F23 (VDD_ARM_IN), U101.J22 (VDD_ARM_IN), U101.J23 (VDD_ARM_IN)
/power/BAT+: J1.1, J1.2, J1.3, J1.4, R22.1, U8.19 (BATSENS+), U8.20 (CSN)
/power/BAT_NTC: J1.5, R20.1, U8.10 (NTC)
/power/INTVCC: C33.2, U8.2 (INTVCC), U8.18 (CELLS1)
/power/VCC2P5: C32.2, U8.8 (VCC2P5), U8.17 (CELLS0)
/usb/OCI1B: U601.13 (OCS_N1), U602.3 (~FLG)
/usb/OCI2B: U601.17 (OCS_N2), U603.3 (~FLG)
/usb/PPON1: U601.12 (PRTPWR1/BC_EN1), U602.4 (EN)
/usb/PPON2: U601.16 (PRTPWR2/BC_EN2), U603.4 (EN)
/usb/TYPEC_DN: J603.A7 (D-), J603.B7 (D-), L601.4, U605.3 (I/O2), U605.4 (I/O2)
/usb/TYPEC_DP: J603.A6 (D+), J603.B6 (D+), L601.3, U605.1 (I/O1), U605.6 (I/O1)
/usb/USB_DM1: J601.2 (D-), U601.1 (USBDM_DN1/PRT_DIS_M1)
/usb/USB_DM2: J602.2 (D-), U601.3 (USBDM_DN2/PRT_DIS_M2)
/usb/USB_DP1: J601.3 (D+), U601.2 (USBDP_DN1/PRT_DIS_P1)
/usb/USB_DP2: J602.3 (D+), U601.4 (USBDP_DN2/PRT_DIS_P2)
/usb/VBUS1: C619.1, J601.1 (VBUS), U602.1 (OUT)
/usb/VBUS2: C620.1, J602.1 (VBUS), U603.1 (OUT)
AP_WAKE_BT: U101.T1 (GPIO_IO11), U901.6 (BT_WAKE)
ARM_EN: U5.4 (RUN), U301.42 (PIO1_3)
BT_CFG_1: RN101.4 (R4.1), U101.A22 (LCD1_DATA1), U502.36 (DATA1)
BT_CFG_2: RN103.5 (R4.2), U101.B22 (LCD1_DATA2), U502.37 (DATA2)
BT_CFG_3: RN103.6 (R3.2), U101.A23 (LCD1_DATA3), U502.38 (DATA3)
BT_CFG_4: RN101.3 (R3.1), U101.C22 (LCD1_DATA4), U502.39 (DATA4)
BT_CFG_5: RN103.8 (R1.2), U101.B23 (LCD1_DATA5), U502.40 (DATA5)
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

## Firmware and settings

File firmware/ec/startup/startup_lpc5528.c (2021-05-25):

//*****************************************************************************
// LPC5528_cm33_core0 startup code for use with MCUXpresso IDE
//
// Version : 160420
//*****************************************************************************
//
// Copyright 2016-2020 NXP
// All rights reserved.
//
// SPDX-License-Identifier: BSD-3-Clause
//*****************************************************************************

#if defined (DEBUG)
#pragma GCC push_options
#pragma GCC optimize ("Og")
#endif // (DEBUG)

#if defined (__cplusplus)
#ifdef __REDLIB__
#error Redlib does not support C++
#else
//*****************************************************************************
//
// The entry point for the C++ library startup
//
//*****************************************************************************
extern "C" {
    extern void __libc_init_array(void);
}
#endif
#endif

#define WEAK __attribute__ ((weak))
#define WEAK_AV __attribute__ ((weak, section(".after_vectors")))
#define ALIAS(f) __attribute__ ((weak, alias (#f)))

//*****************************************************************************
#if defined (__cplusplus)
extern "C" {
#endif

//*****************************************************************************
// Variable to store CRP value in. Will be placed automatically
// by the linker when "Enable Code Read Protect" selected.
// See crp.h header for more information
//*****************************************************************************
//*****************************************************************************
// Declaration of external SystemInit function
//*****************************************************************************
#if defined (__USE_CMSIS)
extern void SystemInit(void);
#endif // (__USE_CMSIS)

//*****************************************************************************
// Forward declaration of the core exception handlers.
// When the application defines a handler (with the same name), this will
// automatically take precedence over these weak definitions.
// If your application is a C++ one, then any interrupt handlers defined
// in C++ files within in your main application will need to have C linkage
// rather than C++ linkage. To do this, make sure that you are using extern "C"
// { .... } around the interrupt handler within your main application code.
//*****************************************************************************
     void ResetISR(void);
WEAK void NMI_Handler(void);
WEAK void HardFault_Handler(void);
WEAK void MemManage_Handler(void);
WEAK void BusFault_Handler(void);
WEAK void UsageFault_Handler(void);
WEAK void SecureFault_Handler(void);
WEAK void SVC_Handler(void);
WEAK void DebugMon_Handler(void);
WEAK void PendSV_Handler(void);
WEAK void SysTick_Handler(void);
WEAK void IntDefaultHandler(void);

//*****************************************************************************
// Forward declaration of the application IRQ handlers. When the application
// defines a handler (with the same name), this will automatically take
// precedence over weak definitions below
//*****************************************************************************
WEAK void WDT_BOD_IRQHandler(void);
WEAK void DMA0_IRQHandler(void);
WEAK void GINT0_IRQHandler(void);
WEAK void GINT1_IRQHandler(void);
WEAK void PIN_INT0_IRQHandler(void);
WEAK void PIN_INT1_IRQHandler(void);
WEAK void PIN_INT2_IRQHandler(void);
WEAK void PIN_INT3_IRQHandler(void);
WEAK void UTICK0_IRQHandler(void);
WEAK void MRT0_IRQHandler(void);
WEAK void CTIMER0_IRQHandler(void);
WEAK void CTIMER1_IRQHandler(void);
WEAK void SCT0_IRQHandler(void);
WEAK void CTIMER3_IRQHandler(void);
WEAK void FLEXCOMM0_IRQHandler(void);
WEAK void FLEXCOMM1_IRQHandler(void);
WEAK void FLEXCOMM2_IRQHandler(void);
WEAK void FLEXCOMM3_IRQHandler(void);
WEAK void FLEXCOMM4_IRQHandler(void);
WEAK void FLEXCOMM5_IRQHandler(void);
WEAK void FLEXCOMM6_IRQHandler(void);
WEAK void FLEXCOMM7_IRQHandler(void);
WEAK void ADC0_IRQHandler(void);
WEAK void Reserved39_IRQHandler(void);
WEAK void ACMP_IRQHandler(void);
WEAK void Reserved41_IRQHandler(void);
WEAK void Reserved42_IRQHandler(void);
WEAK void USB0_NEEDCLK_IRQHandler(void);
WEAK void USB0_IRQHandler(void);
WEAK void RTC_IRQHandler(void);
WEAK void Reserved46_IRQHandler(void);
WEAK void Reserved47_IRQHandler(void);
WEAK void PIN_INT4_IRQHandler(void);
WEAK void PIN_INT5_IRQHandler(void);
WEAK void PIN_INT6_IRQHandler(void);
WEAK void PIN_INT7_IRQHandler(void);
WEAK void CTIMER2_IRQHandler(void);
WEAK void CTIMER4_IRQHandler(void);
WEAK void OS_EVENT_IRQHandler(void);
WEAK void Reserved55_IRQHandler(void);
WEAK void Reserved56_IRQHandler(void);
WEAK void Reserved57_IRQHandler(void);
WEAK void SDIO_IRQHandler(void);
WEAK void Reserved59_IRQHandler(void);
WEAK void Reserved60_IRQHandler(void);
WEAK void Reserved61_IRQHandler(void);
WEAK void USB1_PHY_IRQHandler(void);
WEAK void USB1_IRQHandler(void);
WEAK void USB1_NEEDCLK_IRQHandler(void);
WEAK void SEC_HYPERVISOR_CALL_IRQHandler(void);
WEAK void SEC_GPIO_INT0_IRQ0_IRQHandler(void);
WEAK void SEC_GPIO_INT0_IRQ1_IRQHandler(void);
WEAK void PLU_IRQHandler(void);
WEAK void SEC_VIO_IRQHandler(void);
WEAK void Reserved70_IRQHandler(void);
WEAK void CASER_IRQHandler(void);
WEAK void Reserved72_IRQHandler(void);
WEAK void PQ_IRQHandler(void);
WEAK void DMA1_IRQHandler(void);
WEAK void FLEXCOMM8_IRQHandler(void);

//*****************************************************************************
// Forward declaration of the driver IRQ handlers. These are aliased
// to the IntDefaultHandler, which is a 'forever' loop. When the driver
// defines a handler (with the same name), this will automatically take
// precedence over these weak definitions
//*****************************************************************************
void WDT_BOD_DriverIRQHandler(void) ALIAS(IntDefaultHandler);
void DMA0_DriverIRQHandler(void) ALIAS(IntDefaultHandler);
void GINT0_DriverIRQHandler(void) ALIAS(IntDefaultHandler);
void GINT1_DriverIRQHandler(void) ALIAS(IntDefaultHandler);
void PIN_INT0_DriverIRQHandler(void) ALIAS(IntDefaultHandler);
void PIN_INT1_DriverIRQHandler(void) ALIAS(IntDefaultHandler);
void PIN_INT2_DriverIRQHandler(void) ALIAS(IntDefaultHandler);
void PIN_INT3_DriverIRQHandler(void) ALIAS(IntDefaultHandler);
void UTICK0_DriverIRQHandler(void) ALIAS(IntDefaultHandler);
void MRT0_DriverIRQHandler(void) ALIAS(IntDefaultHandler);
void CTIMER0_DriverIRQHandler(void) ALIAS(IntDefaultHandler);
void CTIMER1_DriverIRQHandler(void) ALIAS(IntDefaultHandler);
void SCT0_DriverIRQHandler(void) ALIAS(IntDefaultHandler);
void CTIMER3_DriverIRQHandler(void) ALIAS(IntDefaultHandler);
void FLEXCOMM0_DriverIRQHandler(void) ALIAS(IntDefaultHandler);
void FLEXCOMM1_DriverIRQHandler(void) ALIAS(IntDefaultHandler);
void FLEXCOMM2_DriverIRQHandler(void) ALIAS(IntDefaultHandler);
void FLEXCOMM3_DriverIRQHandler(void) ALIAS(IntDefaultHandler);
void FLEXCOMM4_DriverIRQHandler(void) ALIAS(IntDefaultHandler);
void FLEXCOMM5_DriverIRQHandler(void) ALIAS(IntDefaultHandler);
void FLEXCOMM6_DriverIRQHandler(void) ALIAS(IntDefaultHandler);
void FLEXCOMM7_DriverIRQHandler(void) ALIAS(IntDefaultHandler);
void ADC0_DriverIRQHandler(void) ALIAS(IntDefaultHandler);
void Reserved39_DriverIRQHandler(void) ALIAS(IntDefaultHandler);
void ACMP_DriverIRQHandler(void) ALIAS(IntDefaultHandler);
void Reserved41_DriverIRQHandler(void) ALIAS(IntDefaultHandler);
void Reserved42_DriverIRQHandler(void) ALIAS(IntDefaultHandler);
void USB0_NEEDCLK_DriverIRQHandler(void) ALIAS(IntDefaultHandler);
void USB0_DriverIRQHandler(void) ALIAS(IntDefaultHandler);
void RTC_DriverIRQHandler(void) ALIAS(IntDefaultHandler);
void Reserved46_DriverIRQHandler(void) ALIAS(IntDefaultHandler);
void Reserved47_DriverIRQHandler(void) ALIAS(IntDefaultHandler);
void PIN_INT4_DriverIRQHandler(void) ALIAS(IntDefaultHandler);
void PIN_INT5_DriverIRQHandler(void) ALIAS(IntDefaultHandler);
void PIN_INT6_DriverIRQHandler(void) ALIAS(IntDefaultHandler);
void PIN_INT7_DriverIRQHandler(void) ALIAS(IntDefaultHandler);
void CTIMER2_DriverIRQHandler(void) ALIAS(IntDefaultHandler);
void CTIMER4_DriverIRQHandler(void) ALIAS(IntDefaultHandler);
void OS_EVENT_DriverIRQHandler(void) ALIAS(IntDefaultHandler);
void Reserved55_DriverIRQHandler(void) ALIAS(IntDefaultHandler);
void Reserved56_DriverIRQHandler(void) ALIAS(IntDefaultHandler);
void Reserved57_DriverIRQHandler(void) ALIAS(IntDefaultHandler);
void SDIO_DriverIRQHandler(void) ALIAS(IntDefaultHandler);
void Reserved59_DriverIRQHandler(void) ALIAS(IntDefaultHandler);
void Reserved60_DriverIRQHandler(void) ALIAS(IntDefaultHandler);
void Reserved61_DriverIRQHandler(void) ALIAS(IntDefaultHandler);
void USB1_PHY_DriverIRQHandler(void) ALIAS(IntDefaultHandler);
void USB1_DriverIRQHandler(void) ALIAS(IntDefaultHandler);
void USB1_NEEDCLK_DriverIRQHandler(void) ALIAS(IntDefaultHandler);
void SEC_HYPERVISOR_CALL_DriverIRQHandler(void) ALIAS(IntDefaultHandler);
void SEC_GPIO_INT0_IRQ0_DriverIRQHandler(void) ALIAS(IntDefaultHandler);
void SEC_GPIO_INT0_IRQ1_DriverIRQHandler(void) ALIAS(IntDefaultHandler);
void PLU_DriverIRQHandler(void) ALIAS(IntDefaultHandler);
void SEC_VIO_DriverIRQHandler(void) ALIAS(IntDefaultHandler);
void Reserved70_DriverIRQHandler(void) ALIAS(IntDefaultHandler);
void CASER_DriverIRQHandler(void) ALIAS(IntDefaultHandler);
void Reserved72_DriverIRQHandler(void) ALIAS(IntDefaultHandler);
void PQ_DriverIRQHandler(void) ALIAS(IntDefaultHandler);
void DMA1_DriverIRQHandler(void) ALIAS(IntDefaultHandler);
void FLEXCOMM8_DriverIRQHandler(void) ALIAS(IntDefaultHandler);

//*****************************************************************************
// The entry point for the application.
// __main() is the entry point for Redlib based applications
// main() is the entry point for Newlib based applications
//*****************************************************************************
#if defined (__REDLIB__)
extern void __main(void);
#endif
extern int main(void);

//*****************************************************************************
// External declaration for the pointer to the stack top from the Linker Script
//*****************************************************************************
extern void _vStackTop(void);
//*****************************************************************************
// External declaration for LPC MCU vector table checksum from  Linker Script
//*****************************************************************************
WEAK extern void __valid_user_code_checksum();

//*****************************************************************************
//*****************************************************************************
#if defined (__cplusplus)
} // extern "C"
#endif
//*****************************************************************************
// The vector table.
// This relies on the linker script to place at correct location in memory.
//*****************************************************************************



extern void (* const g_pfnVectors[])(void);
extern void * __Vectors __attribute__ ((alias ("g_pfnVectors")));

__attribute__ ((used, section(".isr_vector")))
void (* const g_pfnVectors[])(void) = {
    // Core Level - CM33
    &_vStackTop,                       // The initial stack pointer
    ResetISR,                          // The reset handler
    NMI_Handler,                       // The NMI handler
    HardFault_Handler,                 // The hard fault handler
    MemManage_Handler,                 // The MPU fault handler
    BusFault_Handler,                  // The bus fault handler
    UsageFault_Handler,                // The usage fault handler
    SecureFault_Handler,               // The secure fault handler
    0,                                 // ECRP
    0,                                 // Reserved
    0,                                 // Reserved
    SVC_Handler,                       // SVCall handler
    DebugMon_Handler,                  // Debug monitor handler
    0,                                 // Reserved
    PendSV_Handler,                    // The PendSV handler
    SysTick_Handler,                   // The SysTick handler

    // Chip Level - LPC5528_cm33_core0
    WDT_BOD_IRQHandler,              // 16: Windowed watchdog timer, Brownout detect, Flash interrupt
    DMA0_IRQHandler,                 // 17: DMA0 controller
    GINT0_IRQHandler,                // 18: GPIO group 0
    GINT1_IRQHandler,                // 19: GPIO group 1
    PIN_INT0_IRQHandler,             // 20: Pin interrupt 0 or pattern match engine slice 0
    PIN_INT1_IRQHandler,             // 21: Pin interrupt 1or pattern match engine slice 1
    PIN_INT2_IRQHandler,             // 22: Pin interrupt 2 or pattern match engine slice 2
    PIN_INT3_IRQHandler,             // 23: Pin interrupt 3 or pattern match engine slice 3
    UTICK0_IRQHandler,               // 24: Micro-tick Timer
    MRT0_IRQHandler,                 // 25: Multi-rate timer
    CTIMER0_IRQHandler,              // 26: Standard counter/timer CTIMER0
    CTIMER1_IRQHandler,              // 27: Standard counter/timer CTIMER1
    SCT0_IRQHandler,                 // 28: SCTimer/PWM
    CTIMER3_IRQHandler,              // 29: Standard counter/timer CTIMER3
    FLEXCOMM0_IRQHandler,            // 30: Flexcomm Interface 0 (USART, SPI, I2C, I2S, FLEXCOMM)
    FLEXCOMM1_IRQHandler,            // 31: Flexcomm Interface 1 (USART, SPI, I2C, I2S, FLEXCOMM)
    FLEXCOMM2_IRQHandler,            // 32: Flexcomm Interface 2 (USART, SPI, I2C, I2S, FLEXCOMM)
    FLEXCOMM3_IRQHandler,            // 33: Flexcomm Interface 3 (USART, SPI, I2C, I2S, FLEXCOMM)
    FLEXCOMM4_IRQHandler,            // 34: Flexcomm Interface 4 (USART, SPI, I2C, I2S, FLEXCOMM)
    FLEXCOMM5_IRQHandler,            // 35: Flexcomm Interface 5 (USART, SPI, I2C, I2S, FLEXCOMM)
    FLEXCOMM6_IRQHandler,            // 36: Flexcomm Interface 6 (USART, SPI, I2C, I2S, FLEXCOMM)
    FLEXCOMM7_IRQHandler,            // 37: Flexcomm Interface 7 (USART, SPI, I2C, I2S, FLEXCOMM)
    ADC0_IRQHandler,                 // 38: ADC0
    Reserved39_IRQHandler,           // 39: Reserved interrupt
    ACMP_IRQHandler,                 // 40: ACMP  interrupts
    Reserved41_IRQHandler,           // 41: Reserved interrupt
    Reserved42_IRQHandler,           // 42: Reserved interrupt
    USB0_NEEDCLK_IRQHandler,         // 43: USB Activity Wake-up Interrupt
    USB0_IRQHandler,                 // 44: USB device
    RTC_IRQHandler,                  // 45: RTC alarm and wake-up interrupts
    Reserved46_IRQHandler,           // 46: Reserved interrupt
    Reserved47_IRQHandler,           // 47: Reserved interrupt
    PIN_INT4_IRQHandler,             // 48: Pin interrupt 4 or pattern match engine slice 4 int
    PIN_INT5_IRQHandler,             // 49: Pin interrupt 5 or pattern match engine slice 5 int
    PIN_INT6_IRQHandler,             // 50: Pin interrupt 6 or pattern match engine slice 6 int
    PIN_INT7_IRQHandler,             // 51: Pin interrupt 7 or pattern match engine slice 7 int
    CTIMER2_IRQHandler,              // 52: Standard counter/timer CTIMER2
    CTIMER4_IRQHandler,              // 53: Standard counter/timer CTIMER4
    OS_EVENT_IRQHandler,             // 54: OSEVTIMER0 and OSEVTIMER0_WAKEUP interrupts
    Reserved55_IRQHandler,           // 55: Reserved interrupt
    Reserved56_IRQHandler,           // 56: Reserved interrupt
    Reserved57_IRQHandler,           // 57: Reserved interrupt
    SDIO_IRQHandler,                 // 58: SD/MMC
    Reserved59_IRQHandler,           // 59: Reserved interrupt
    Reserved60_IRQHandler,           // 60: Reserved interrupt
    Reserved61_IRQHandler,           // 61: Reserved interrupt
    USB1_PHY_IRQHandler,             // 62: USB1_PHY
    USB1_IRQHandler,                 // 63: USB1 interrupt
    USB1_NEEDCLK_IRQHandler,         // 64: USB1 activity
    SEC_HYPERVISOR_CALL_IRQHandler,  // 65: SEC_HYPERVISOR_CALL interrupt
    SEC_GPIO_INT0_IRQ0_IRQHandler,   // 66: SEC_GPIO_INT0_IRQ0 interrupt
    SEC_GPIO_INT0_IRQ1_IRQHandler,   // 67: SEC_GPIO_INT0_IRQ1 interrupt
    PLU_IRQHandler,                  // 68: PLU interrupt
    SEC_VIO_IRQHandler,              // 69: SEC_VIO interrupt
    Reserved70_IRQHandler,           // 70: Reserved interrupt
    CASER_IRQHandler,                // 71: CASPER interrupt
    Reserved72_IRQHandler,           // 72: Reserved interrupt
    PQ_IRQHandler,                   // 73: PQ interrupt
    DMA1_IRQHandler,                 // 74: DMA1 interrupt
    FLEXCOMM8_IRQHandler,            // 75: Flexcomm Interface 8 (SPI, , FLEXCOMM)


}; /* End of g_pfnVectors */

//*****************************************************************************
// Functions to carry out the initialization of RW and BSS data sections. These
// are written as separate functions rather than being inlined within the
// ResetISR() function in order to cope with MCUs with multiple banks of
// memory.
//*****************************************************************************
__attribute__ ((section(".after_vectors.init_data")))
void data_init(unsigned int romstart, unsigned int start, unsigned int len) {
    unsigned int *pulDest = (unsigned int*) start;
    unsigned int *pulSrc = (unsigned int*) romstart;
    unsigned int loop;
    for (loop = 0; loop < len; loop = loop + 4)
        *pulDest++ = *pulSrc++;
}

__attribute__ ((section(".after_vectors.init_bss")))
void bss_init(unsigned int start, unsigned int len) {
    unsigned int *pulDest = (unsigned int*) start;
    unsigned int loop;
    for (loop = 0; loop < len; loop = loop + 4)
        *pulDest++ = 0;
}

//*****************************************************************************
// The following symbols are constructs generated by the linker, indicating
// the location of various points in the "Global Section Table". This table is
// created by the linker via the Code Red managed linker script mechanism. It
// contains the load address, execution address and length of each RW data
// section and the execution and length of each BSS (zero initialized) section.
//*****************************************************************************
extern unsigned int __data_section_table;
extern unsigned int __data_section_table_end;
extern unsigned int __bss_section_table;
extern unsigned int __bss_section_table_end;

//*****************************************************************************
// Reset entry point for your code.
// Sets up a simple runtime environment and initializes the C/C++
// library.
//*****************************************************************************
__attribute__ ((section(".after_vectors.reset")))
void ResetISR(void) {

    // Disable interrupts
    __asm volatile ("cpsid i");



#if defined (__USE_CMSIS)
// If __USE_CMSIS defined, then call CMSIS SystemInit code
    SystemInit();

#endif // (__USE_CMSIS)

    //
    // Copy the data sections from flash to SRAM.
    //
    unsigned int LoadAddr, ExeAddr, SectionLen;
    unsigned int *SectionTableAddr;

    // Load base address of Global Section Table
    SectionTableAddr = &__data_section_table;

    // Copy the data sections from flash to SRAM.
    while (SectionTableAddr < &__data_section_table_end) {
        LoadAddr = *SectionTableAddr++;
        ExeAddr = *SectionTableAddr++;
        SectionLen = *SectionTableAddr++;
        data_init(LoadAddr, ExeAddr, SectionLen);
    }

    // At this point, SectionTableAddr = &__bss_section_table;
    // Zero fill the bss segment
    while (SectionTableAddr < &__bss_section_table_end) {
        ExeAddr = *SectionTableAddr++;
        SectionLen = *SectionTableAddr++;
        bss_init(ExeAddr, SectionLen);
    }


#if !defined (__USE_CMSIS)
// Assume that if __USE_CMSIS defined, then CMSIS SystemInit code
// will setup the VTOR register

    // Check to see if we are running the code from a non-zero
    // address (eg RAM, external flash), in which case we need
    // to modify the VTOR register to tell the CPU that the
    // vector table is located at a non-0x0 address.
    unsigned int * pSCB_VTOR = (unsigned int *) 0xE000ED08;
    if ((unsigned int *)g_pfnVectors!=(unsigned int *) 0x00000000) {
        *pSCB_VTOR = (unsigned int)g_pfnVectors;
    }
#endif // (__USE_CMSIS)
#if defined (__cplusplus)
    //
    // Call C++ library initialisation
    //
    __libc_init_array();
#endif

    // Reenable interrupts
    __asm volatile ("cpsie i");

#if defined (__REDLIB__)
    // Call the Redlib library, which in turn calls main()
    __main();
#else
    main();
#endif

    //
    // main() shouldn't return, but if it does, we'll just enter an infinite loop
    //
    while (1) {
        ;
    }
}

//*****************************************************************************
// Default core exception handlers. Override the ones here by defining your own
// handler routines in your application code.
//*****************************************************************************
WEAK_AV void NMI_Handler(void)
{ while(1) {}
}

WEAK_AV void HardFault_Handler(void)
{ while(1) {}
}

WEAK_AV void MemManage_Handler(void)
{ while(1) {}
}

WEAK_AV void BusFault_Handler(void)
{ while(1) {}
}

WEAK_AV void UsageFault_Handler(void)
{ while(1) {}
}

WEAK_AV void SecureFault_Handler(void)
{ while(1) {}
}

WEAK_AV void SVC_Handler(void)
{ while(1) {}
}

WEAK_AV void DebugMon_Handler(void)
{ while(1) {}
}

WEAK_AV void PendSV_Handler(void)
{ while(1) {}
}

WEAK_AV void SysTick_Handler(void)
{ while(1) {}
}

//*****************************************************************************
// Processor ends up here if an unexpected interrupt occurs or a specific
// handler is not present in the application code.
//*****************************************************************************
WEAK_AV void IntDefaultHandler(void)
{ while(1) {}
}
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

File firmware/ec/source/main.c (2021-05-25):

/*
 * Copyright 2016-2021 NXP
 * All rights reserved.
 *
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
 * o Neither the name of NXP Semiconductor, Inc. nor the names of its
 *   contributors may be used to endorse or promote products derived from this
 *   software without specific prior written permission.
 *
 * THIS SOFTWARE IS PROVIDED BY THE COPYRIGHT HOLDERS AND CONTRIBUTORS "AS IS" AND
 * ANY EXPRESS OR IMPLIED WARRANTIES, INCLUDING, BUT NOT LIMITED TO, THE IMPLIED
 * WARRANTIES OF MERCHANTABILITY AND FITNESS FOR A PARTICULAR PURPOSE ARE
 * DISCLAIMED. IN NO EVENT SHALL THE COPYRIGHT HOLDER OR CONTRIBUTORS BE LIABLE FOR
 * ANY DIRECT, INDIRECT, INCIDENTAL, SPECIAL, EXEMPLARY, OR CONSEQUENTIAL DAMAGES
 * (INCLUDING, BUT NOT LIMITED TO, PROCUREMENT OF SUBSTITUTE GOODS OR SERVICES;
 * LOSS OF USE, DATA, OR PROFITS; OR BUSINESS INTERRUPTION) HOWEVER CAUSED AND ON
 * ANY THEORY OF LIABILITY, WHETHER IN CONTRACT, STRICT LIABILITY, OR TORT
 * (INCLUDING NEGLIGENCE OR OTHERWISE) ARISING IN ANY WAY OUT OF THE USE OF THIS
 * SOFTWARE, EVEN IF ADVISED OF THE POSSIBILITY OF SUCH DAMAGE.
 */

/**
 * @file    ec.c
 * @brief   Application entry point.
 */
#include <stdio.h>
#include "board.h"
#include "peripherals.h"
#include "pin_mux.h"
#include "clock_config.h"
#include "LPC5528.h"
#include "fsl_debug_console.h"
#include "usb_app.h"

/*
 * @brief   Application entry point.
 */
int main(void) {

    /* Init board hardware. */
    BOARD_InitBootPins();
    BOARD_InitBootClocks();
    BOARD_InitBootPeripherals();

    PRINTF("Hello World\n");

    debug_usb_init();

    while(1) {
        debug_usb_task();
    }
    return 0 ;
}

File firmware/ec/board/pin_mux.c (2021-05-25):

/***********************************************************************************************************************
 * This file was generated by the MCUXpresso Config Tools. Any manual edits made to this file
 * will be overwritten if the respective MCUXpresso Config Tools is used to update this file.
 **********************************************************************************************************************/

/* clang-format off */
/*
 * TEXT BELOW IS USED AS SETTING FOR TOOLS *************************************
!!GlobalInfo
product: Pins v9.0
processor: LPC5528
package_id: LPC5528JBD100
mcu_data: ksdk2_0
processor_version: 9.0.1
pin_labels:
- {pin_num: '54', pin_signal: PIO0_0/FC3_SCK/CTIMER0_MAT0/SCT_GPI0/SD1_CARD_INT_N/SECURE_GPIO0_0/ACMP0_A, label: KSI0, identifier: KSI0}
- {pin_num: '7', pin_signal: PIO0_1/FC3_CTS_SDA_SSEL0/CT_INP0/SCT_GPI1/SD1_CLK/CMP0_OUT/SECURE_GPIO0_1, label: KSI1, identifier: KSI1}
- {pin_num: '81', pin_signal: PIO0_2/FC3_TXD_SCL_MISO_WS/CT_INP1/SCT0_OUT0/SCT_GPI2/SECURE_GPIO0_2, label: KSI2, identifier: KSI2}
- {pin_num: '83', pin_signal: PIO0_3/FC3_RXD_SDA_MOSI_DATA/CTIMER0_MAT1/SCT0_OUT1/SCT_GPI3/SECURE_GPIO0_3, label: KSI3, identifier: KSI3}
- {pin_num: '86', pin_signal: PIO0_4/FC4_SCK/CT_INP12/SCT_GPI4/FC3_CTS_SDA_SSEL0/SECURE_GPIO0_4, label: KSI4, identifier: KSI4}
- {pin_num: '88', pin_signal: PIO0_5/FC4_RXD_SDA_MOSI_DATA/CTIMER3_MAT0/SCT_GPI5/FC3_RTS_SCL_SSEL1/MCLK/SECURE_GPIO0_5, label: KSI5, identifier: KSI5}
- {pin_num: '89', pin_signal: PIO0_6/FC3_SCK/CT_INP13/CTIMER4_MAT0/SCT_GPI6/SECURE_GPIO0_6, label: KSI6, identifier: KSI6}
- {pin_num: '6', pin_signal: PIO0_7/FC3_RTS_SCL_SSEL1/SD0_CLK/FC5_SCK/FC1_SCK/SECURE_GPIO0_7, label: KSI7, identifier: KSI7}
- {pin_num: '26', pin_signal: PIO0_8/FC3_SSEL3/SD0_CMD/FC5_RXD_SDA_MOSI_DATA/SWO/SECURE_GPIO0_8, label: PMIC_STBY_REQ, identifier: PMIC_STBY_REQ}
- {pin_num: '55', pin_signal: PIO0_9/FC3_SSEL2/SD0_POW_EN/FC5_TXD_SCL_MISO_WS/SECURE_GPIO0_9/ACMP0_B, label: PMIC_ON_REQ, identifier: PMIC_ON_REQ}
- {pin_num: '21', pin_signal: PIO0_10/FC6_SCK/CT_INP10/CTIMER2_MAT0/FC1_TXD_SCL_MISO_WS/SCT0_OUT2/SWO/SECURE_GPIO0_10/ADC0_1, label: LED, identifier: LED}
- {pin_num: '71', pin_signal: PIO0_13/FC1_CTS_SDA_SSEL0/UTICK_CAP0/CT_INP0/SCT_GPI0/FC1_RXD_SDA_MOSI_DATA/PLU_IN0/SECURE_GPIO0_13, label: SDA, identifier: SDA}
- {pin_num: '72', pin_signal: PIO0_14/FC1_RTS_SCL_SSEL1/UTICK_CAP1/CT_INP1/SCT_GPI1/FC1_TXD_SCL_MISO_WS/PLU_IN1/SECURE_GPIO0_14, label: SCL, identifier: SCL}
- {pin_num: '22', pin_signal: PIO0_15/FC6_CTS_SDA_SSEL0/UTICK_CAP2/CT_INP16/SCT0_OUT2/SD0_WR_PRT/SECURE_GPIO0_15/ADC0_2, label: MPU_RST, identifier: MPU_RST}
- {pin_num: '56', pin_signal: PIO0_18/FC4_CTS_SDA_SSEL0/SD0_WR_PRT/CTIMER1_MAT0/SCT0_OUT1/PLU_IN3/SECURE_GPIO0_18/ACMP0_C, label: KSOS0, identifier: KSOS0}
- {pin_num: '90', pin_signal: PIO0_19/FC4_RTS_SCL_SSEL1/UTICK_CAP0/CTIMER0_MAT2/SCT0_OUT2/FC7_TXD_SCL_MISO_WS/PLU_IN4/SECURE_GPIO0_19, label: KSOS1, identifier: KSOS1}
- {pin_num: '74', pin_signal: PIO0_20/FC3_CTS_SDA_SSEL0/CTIMER1_MAT1/CT_INP15/SCT_GPI2/FC7_RXD_SDA_MOSI_DATA/HS_SPI_SSEL0/PLU_IN5/SECURE_GPIO0_20/FC4_TXD_SCL_MISO_WS,
  label: KSOS2, identifier: KSOS2}
- {pin_num: '76', pin_signal: PIO0_21/FC3_RTS_SCL_SSEL1/UTICK_CAP3/CTIMER3_MAT3/SCT_GPI3/FC7_SCK/PLU_CLKIN/SECURE_GPIO0_21, label: KSOS3, identifier: KSOS3}
- {pin_num: '78', pin_signal: PIO0_22/FC6_TXD_SCL_MISO_WS/UTICK_CAP1/CT_INP15/SCT0_OUT3/USB0_VBUS/SD1_D0/PLU_OUT7/SECURE_GPIO0_22, label: KSOE, identifier: KSOE}
- {pin_num: '70', pin_signal: PIO0_24/FC0_RXD_SDA_MOSI_DATA/SD0_D0/CT_INP8/SCT_GPI0/SECURE_GPIO0_24, label: SPI_SCLK, identifier: SPI_SCLK}
- {pin_num: '20', pin_signal: PIO0_23/MCLK/CTIMER1_MAT2/CTIMER3_MAT3/SCT0_OUT4/FC0_CTS_SDA_SSEL0/SD1_D1/SECURE_GPIO0_23/ADC0_0, label: SPI_CS, identifier: SPI_CS}
- {pin_num: '66', pin_signal: PIO0_28/FC0_SCK/SD1_CMD/CT_INP11/SCT0_OUT7/USB0_OVERCURRENTN/PLU_OUT1/SECURE_GPIO0_28, label: LCD_EN, identifier: SPI_;LCD_EN}
- {pin_num: '79', pin_signal: PIO0_25/FC0_TXD_SCL_MISO_WS/SD0_D1/CT_INP9/SCT_GPI1/SECURE_GPIO0_25, label: SPI_MOSI, identifier: SPI_MOSI}
- {pin_num: '60', pin_signal: PIO0_26/FC2_RXD_SDA_MOSI_DATA/CLKOUT/CT_INP14/SCT0_OUT5/USB0_IDVALUE/FC0_SCK/HS_SPI_MOSI/SECURE_GPIO0_26, label: SPI_MISO, identifier: SPI_MISO}
- {pin_num: '92', pin_signal: PIO0_29/FC0_RXD_SDA_MOSI_DATA/SD1_D2/CTIMER2_MAT3/SCT0_OUT8/CMP0_OUT/PLU_OUT2/SECURE_GPIO0_29, label: UART_RX, identifier: UART_RX}
- {pin_num: '94', pin_signal: PIO0_30/FC0_TXD_SCL_MISO_WS/SD1_D3/CTIMER0_MAT0/SCT0_OUT9/SECURE_GPIO0_30, label: UART_TX, identifier: UART_TX}
- {pin_num: '11', pin_signal: PIO1_0/FC0_RTS_SCL_SSEL1/SD0_D3/CT_INP2/SCT_GPI4/PLU_OUT3/ADC0_11, label: USB_OTG_ID, identifier: USB_OTG_ID}
- {pin_num: '59', pin_signal: PIO1_1/FC3_RXD_SDA_MOSI_DATA/CT_INP3/SCT_GPI5/HS_SPI_SSEL1/USB1_OVERCURRENTN/PLU_OUT4, label: EC_INT, identifier: EC_INT}
- {pin_num: '61', pin_signal: PIO1_2/CTIMER0_MAT3/SCT_GPI6/HS_SPI_SCK/USB1_PORTPWRN/PLU_OUT5, label: PWR_EN, identifier: PWR_EN}
- {pin_num: '62', pin_signal: PIO1_3/SCT0_OUT4/HS_SPI_MISO/USB0_PORTPWRN/PLU_OUT6, label: ARM_EN, identifier: ARM_EN}
 * BE CAREFUL MODIFYING THIS COMMENT - IT IS YAML SETTINGS FOR TOOLS ***********
 */
/* clang-format on */

#include "fsl_common.h"
#include "fsl_gpio.h"
#include "fsl_inputmux.h"
#include "pin_mux.h"

/* FUNCTION ************************************************************************************************************
 *
 * Function Name : BOARD_InitBootPins
 * Description   : Calls initialization functions.
 *
 * END ****************************************************************************************************************/
void BOARD_InitBootPins(void)
{
    BOARD_InitPins();
}
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

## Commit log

2021-04-27 - chassis: initial wip C case design
    [C_case.f3d]
2021-04-27 - pcb: initial mb pcb project
    [audio.kicad_sch, connector.kicad_sch, cpu.kicad_sch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]
2021-04-29 - pcb: working on power supply
    [audio.kicad_sch, pcb.kicad_sch, power.kicad_sch]
2021-04-30 - Upgrade KiCad to latest version - Working on PM circuits - Initial USB Type-C support - Initial support for LCD
    [audio.kicad_sch, connector.kicad_sch, cpu.kicad_sch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]
2021-05-01 - pcb: switch to imx7 for the prototype
    [audio.kicad_sch, cpu.kicad_sch, ddr.kicad_sch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]
2021-05-03 - pcb: working on r0p1 sch
    [audio.kicad_sch, connector.kicad_sch, cpu.kicad_sch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]
2021-05-05 - pcb: r0p1 sch draft
    [audio.kicad_sch, cpu.kicad_sch, ddr.kicad_sch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]
2021-05-06 - pcb: start r0p1 layout
    [audio.kicad_sch, cpu.kicad_sch, ddr.kicad_sch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]
2021-05-07 - pcb: components placed
    [audio.kicad_sch, caster.kicad_sch, cpu.kicad_sch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]
2021-05-08 - pcb: ddr layout
    [caster.kicad_sch, pcb.kicad_pcb, pcb.kicad_sch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]
2021-05-12 - pcb: finishing layout r0p1
    [audio.kicad_sch, caster.kicad_sch, cpu.kicad_sch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]
2021-05-12 - pcb: r0p1 pdf pre-release
2021-05-13 - pcb: start working on screen board
    [lcd.kicad_sch, screenboard.kicad_pcb, screenboard.kicad_sch]
2021-05-14 - pcb: migrate to latest kicad, r0p1
    [audio.kicad_sch, caster.kicad_sch, cpu.kicad_sch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]
2021-05-16 - chassis: update design
    [A_case.f3d, B_case.f3d, C_case.f3d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]
2021-05-16 - chassis: initial step files
    [A_case.step, B_case.step, C_case.step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]
2021-05-17 - pcb: add bom for r0p1
2021-05-21 pcb: add some 3D models
2021-05-24 chassis: update C/D case design
    [C_case.f3d, C_case.step, D_case.f3d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]

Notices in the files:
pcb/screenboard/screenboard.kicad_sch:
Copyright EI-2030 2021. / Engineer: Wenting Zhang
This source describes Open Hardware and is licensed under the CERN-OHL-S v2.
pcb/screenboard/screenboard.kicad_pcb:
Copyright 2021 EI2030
